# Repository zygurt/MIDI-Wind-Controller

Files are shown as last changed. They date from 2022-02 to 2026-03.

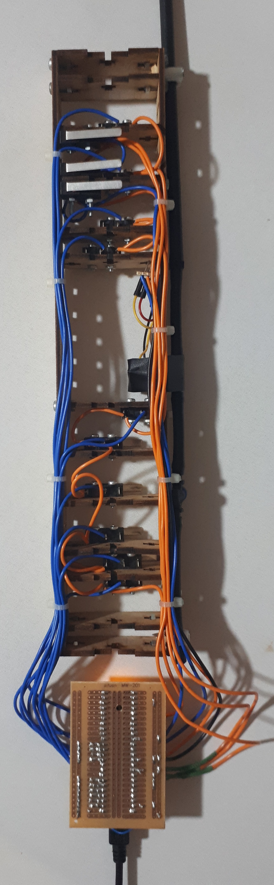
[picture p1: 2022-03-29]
images/Doppler_Sax_Back.jpg

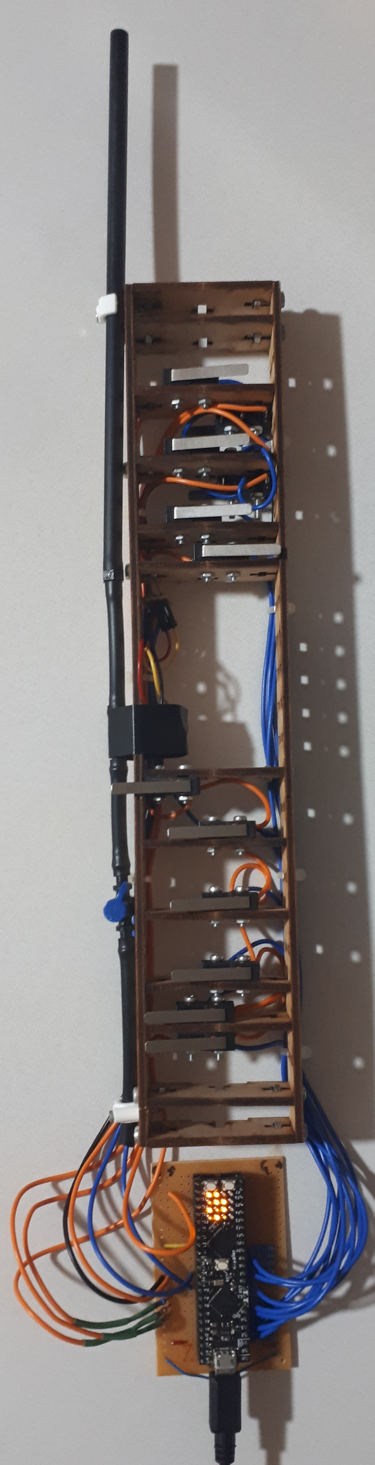
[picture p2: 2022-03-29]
images/Doppler_Sax_Front.jpg

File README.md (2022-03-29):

# MIDI-Wind-Controller

## A brief overview of the repo

- 3D designs contains dxf and svg files.  Basic design was done in Fusion 360 and then exported.
- Datasheets contains datasheets. Woah.
- src contains source code for doppler and Arduino Leonardo implementations, as well as the board schematic.  Currently midi messages are sent over USB, and shows the midi note number in binary on the LED grid on the doppler board.

## Known issues
- Pressing the low C key (D9) causes the doppler to crash.  Reducing the length of the readButtons() switch case to 7 statements stops the crashing.  The error isn't present on the Arduino Leonardo.
- The octave keys give incorrect values for C#. Top 2 octaves are swapped. Again, this error does not occur for the Arduino Leonardo.

Updates are occasionally posted on [Instagram](https://www.instagram.com/zygurt/)

## Current prototype status:
Prototype 2

## Legacy information
Videos about the initial prototype can be found on [Youtube](https://www.youtube.com/watch?v=xT4aQg9pAro&list=PLZOH4oUjroN9ol0y3P3p1gkSgcQwLBbCZ)

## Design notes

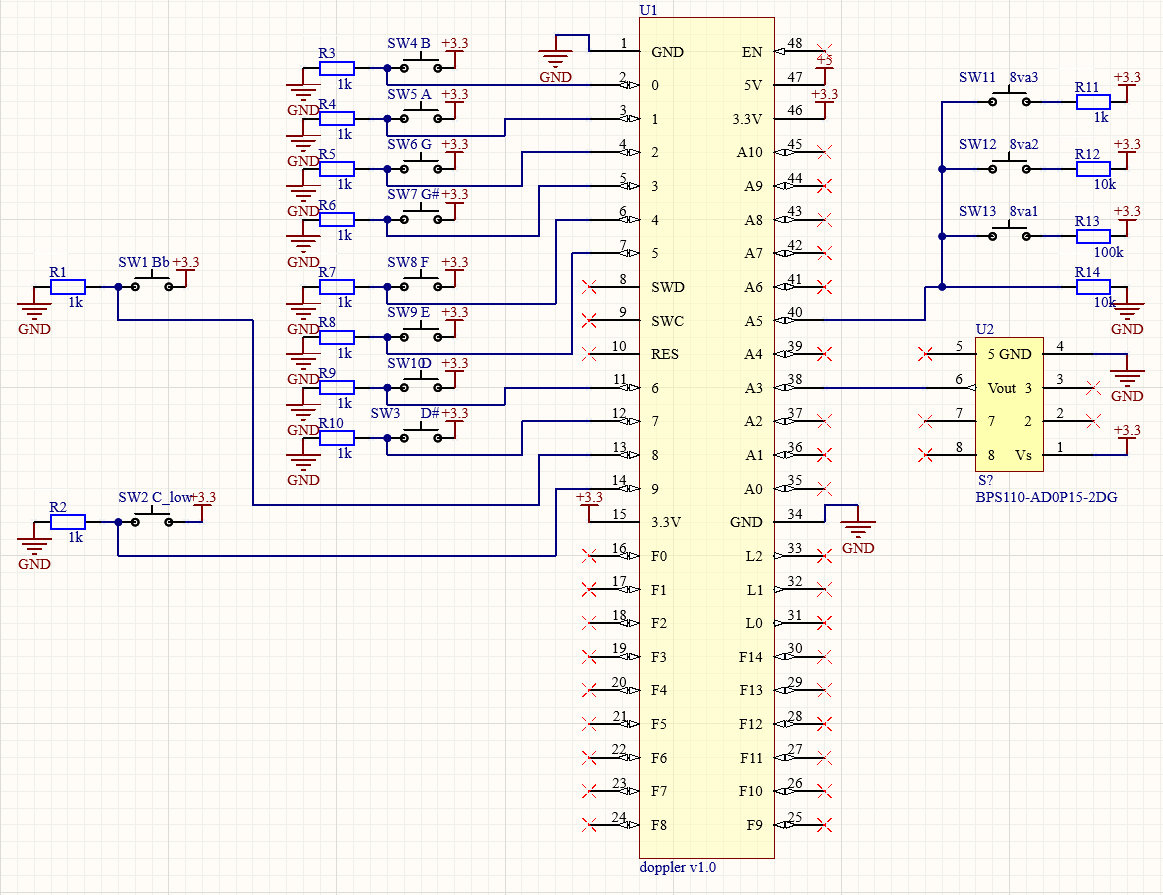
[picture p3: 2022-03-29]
src/Schematic.PNG

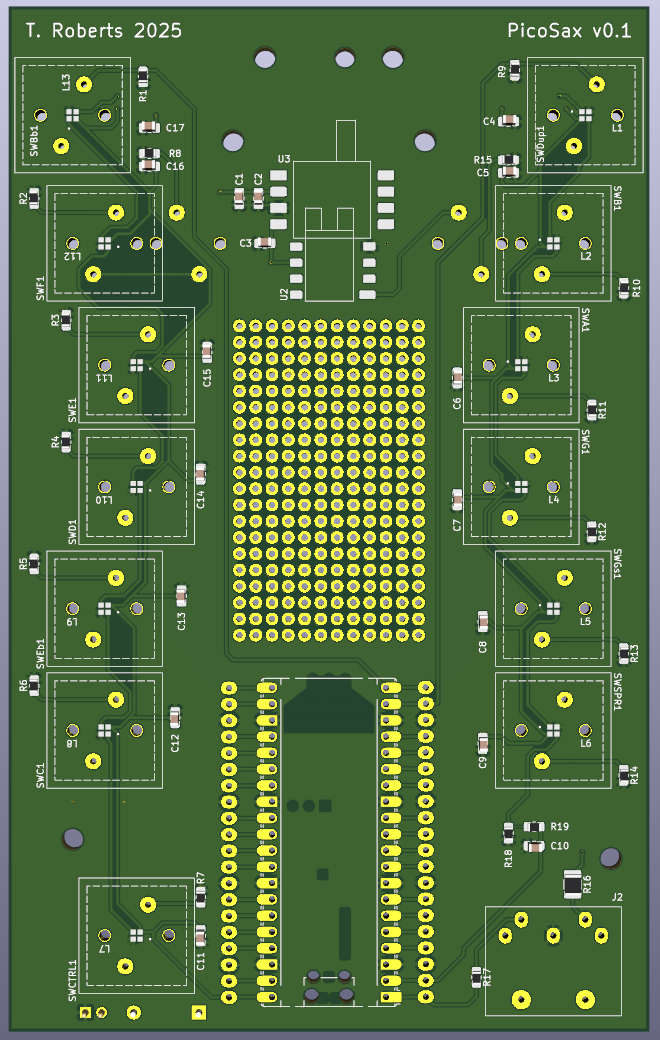
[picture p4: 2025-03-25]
pcb/PicoSax/Images/PCB_3D_Front.PNG

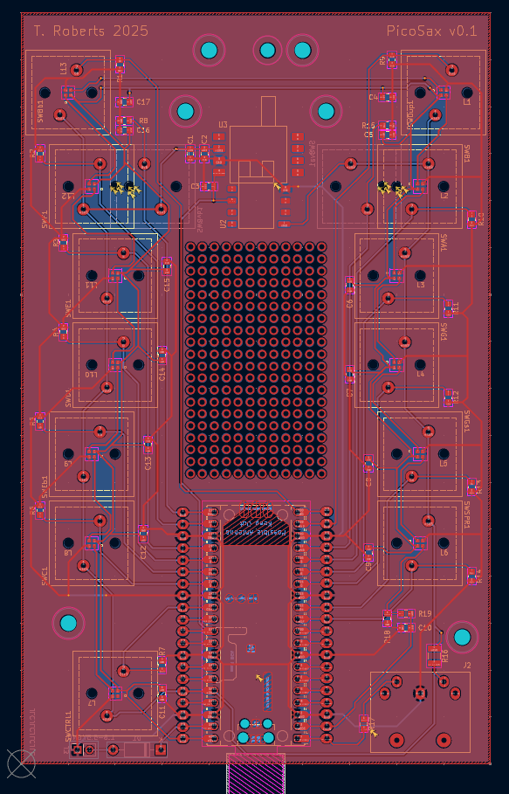
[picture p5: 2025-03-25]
pcb/PicoSax/Images/PCB_Front.PNG

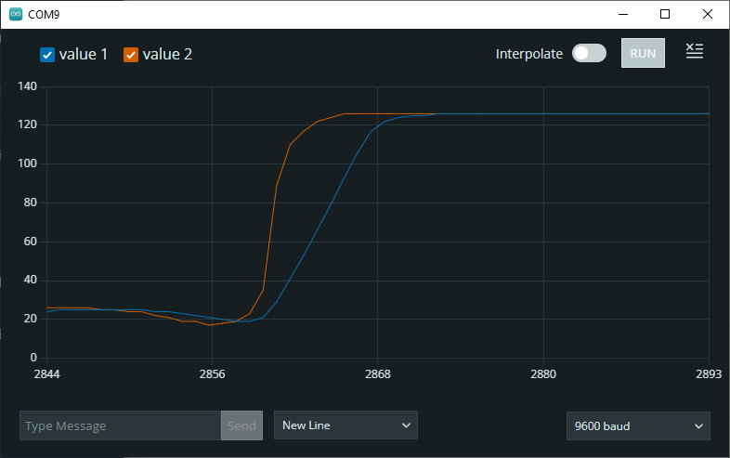
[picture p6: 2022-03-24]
src/BreathRaw_Filtered.PNG

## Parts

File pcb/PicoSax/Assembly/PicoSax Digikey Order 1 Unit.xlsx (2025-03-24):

Index | Quantity | Part Number | Manufacturer Part Number | Description | Customer Reference | Available | Backorder | Unit Price | Extended Price AUD
1 | 14 | 478-08056D104KAT2ACT-ND | 08056D104KAT2A | CAP CER 0.1UF 6.3V X5R 0805 |  | 14 | 0 | 0.07 | 0.98
2 | 1 | 311-1573-1-ND | CC0805KKX5R6BB105 | CAP CER 1UF 10V X5R 0805 |  | 1 | 0 | 0.21 | 0.21
3 | 1 | 732-8016-1-ND | 885012207006 | CAP CER 470PF 10V X7R 0805 |  | 1 | 0 | 0.16 | 0.16
4 | 1 | 732-8021-1-ND | 885012207011 | CAP CER 10000PF 10V X7R 0805 |  | 1 | 0 | 0.16 | 0.16
5 | 4 | S7018-ND | PPTC201LFBN-RC | CONN HDR 20POS 0.1 TIN PCB |  | 4 | 0 | 1.75 | 7.00
6 | 1 | 1N5817DICT-ND | 1N5817-T | DIODE SCHOTTKY 20V 1A DO41 |  | 1 | 0 | 0.35 | 0.35
7 | 1 | 2092-KCDX-5S-N2-ND | KCDX-5S-N2 | CONN RCPT FMALE MINI DIN 5P SLDR |  | 1 | 0 | 2.42 | 2.42
8 | 13 | 1080-1623-1-ND | 19-C47/RSGHBHC-5V01/2T | ADDRESS LED RED/GREEN/BLUE |  | 13 | 0 | 1.041 | 13.53
9 | 17 | RNCP0805FTD10K0CT-ND | RNCP0805FTD10K0 | RES 10K OHM 1% 1/4W 0805 |  | 17 | 0 | 0.024 | 0.41
10 | 1 | 13-RC1210FR-0733RLCT-ND | RC1210FR-0733RL | RES 33 OHM 1% 1/2W 1210 |  | 1 | 0 | 0.17 | 0.17
11 | 1 | RNCP0805FTD10R0CT-ND | RNCP0805FTD10R0 | RES 10 OHM 1% 1/4W 0805 |  | 1 | 0 | 0.16 | 0.16
12 | 1 | MP3V5004GP-ND | MP3V5004GP | SENSOR 0.57PSIG 0.13" 3V 8SOP |  | 0 | 1 | 24.47 | 24.47
 |  |  |  |  |  |  |  |  | 50.02

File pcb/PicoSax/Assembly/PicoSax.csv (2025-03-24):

Reference | Qty | Value | DNP | Exclude from BOM | Size | Footprint | Datasheet | Note | Digikey Part number | Manufacturer Part Number
A1 | 1 | RaspberryPi_Pico |  |  |  | Module:RaspberryPi_Pico_Common_Unspecified | https://datasheets.raspberrypi.com/pico/pico-datasheet.pdf
C1 | 1 | 1uF | >6.3V, X5R |  | 0805 | Capacitor_SMD:C_0805_2012Metric_Pad1.18x1.45mm_HandSolder | ~ |  | CC0805KKX5R6BB105
C2 | 1 | 0.01uF | X7R |  | 0805 | Capacitor_SMD:C_0805_2012Metric_Pad1.18x1.45mm_HandSolder | ~ |  | 885012207011
C3 | 1 | 470pF | X7R |  | 0805 | Capacitor_SMD:C_0805_2012Metric_Pad1.18x1.45mm_HandSolder | ~ |  | 885012207006
C4,C5,C6,C7,C8,C9,C10,C11,C12,C13,C14,C15,C16,C17 | 14 | 0.1uF | X5R |  | 0805 | Capacitor_SMD:C_0805_2012Metric_Pad1.18x1.45mm_HandSolder | ~ |  | 08056D104KAT2A
D1 | 1 | 1N5817 |  |  |  | Diode_THT:D_DO-41_SOD81_P10.16mm_Horizontal | http://www.vishay.com/docs/88525/1n5817.pdf |  | 1N5817DICT-ND - Cut Tape (CT)
J1,J4 | 2 | ~ |  |  | 20 Pins each | MyLibrary:PiPico Header |  |  | S7018-ND | PPTC201LFBN-RC
J2 | 1 | ~ |  |  |  | MyLibrary:MIDI_DIN5 |  |  | 2092-KCDX-5S-N2-ND | KCDX-5S-N2
J3 | 1 | Conn_01x02 | 1 |  | 2 Pin Header | Connector_PinHeader_2.54mm:PinHeader_1x02_P2.54mm_Vertical | ~
L1,L2,L3,L4,L5,L6,L7,L8,L9,L10,L11,L12,L13 | 13 | 19-C47/RSGHBHC-5V01/2T |  |  |  | MyLibrary:19-C47&slash_RSGHBHC-5V01&slash_2T_EVE-M | 19-C47/RSGHBHC-5V01/2T |  | 1080-1623-1-ND - Cut Tape (CT)
R1,R2,R3,R4,R5,R6,R7,R8,R9,R10,R11,R12,R13,R14,R15,R18,R19 | 17 | 10K |  |  | 0805 | Resistor_SMD:R_0805_2012Metric_Pad1.20x1.40mm_HandSolder | ~ |  | RNCP0805FTD10K0CT-ND
R16 | 1 | 33R 0.5W |  |  | 1210 | Resistor_THT:R_Axial_DIN0204_L3.6mm_D1.6mm_P7.62mm_Horizontal | ~ |  | RC1210FR-0733RL
R17 | 1 | 10R 0.25W |  |  | 0805 | Resistor_THT:R_Axial_DIN0204_L3.6mm_D1.6mm_P7.62mm_Horizontal | ~ |  | RNCP0805FTD10R0CT-ND
SW8va1,SW8vb1,SWA1,SWB1,SWBb1,SWC1,SWCTRL1,SWD1,SWDup1,SWE1,SWEb1,SWF1,SWG1,SWGs1,SWSPR1 | 15 | Omron_B3K_L13L |  |  |  | MyLibrary:Omron B3K L13L | ~
U1 | 1 | Perfboard | 1 |  |  | MyLibrary:Perfboard 12x20
U2 | 1 | ~ |  |  |  | MyLibrary:BPS110 AD0P15 |  | Place either U2 or U3
U3 | 1 | ~ |  |  |  | MyLibrary:MP3V5004GP |  | Place either U2 or U3 |  |  | https://au.element14.com/nxp/mp3v5004gp/pressure-sensor-0-3-92kpa-gauge/dp/2776056

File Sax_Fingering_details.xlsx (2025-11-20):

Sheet: Leonardo
Midi Note (Dec) | 73 | 72 | 71 | 70 | 69 | 68 | 67 | 66 | 65 | 64 | 63 | 62
Note | C# | C | B | A# | A | G# | G | F# | F | E | D# | D
B | 0 | 0 | 1 | 1 | 1 | 1 | 1 | 1 | 1 | 1 | 1 | 1 | LSB
A | 0 | 1 | 0 | 1 | 1 | 1 | 1 | 1 | 1 | 1 | 1 | 1
G | 0 | 0 | 0 | 0 | 0 | 1 | 1 | 1 | 1 | 1 | 1 | 1
G# | 0 | 0 | 0 | 0 | 0 | 1 | 0 | 0 | 0 | 0 | 0 | 0
F | 0 | 0 | 0 | 1 | 0 | 0 | 0 | 0 | 1 | 1 | 1 | 1
E | 0 | 0 | 0 | 0 | 0 | 0 | 0 | 1 | 0 | 1 | 1 | 1
D | 0 | 0 | 0 | 0 | 0 | 0 | 0 | 0 | 0 | 0 | 1 | 1
D# | 0 | 0 | 0 | 0 | 0 | 0 | 0 | 0 | 0 | 0 | 1 | 0 | MSB
Note Byte Val | 0 | 2 | 1 | 19 | 3 | 15 | 7 | 39 | 23 | 55 | 247 | 119
 |  |  |  |  | Using Negatives to allow for sqrt(negative)
 |  |  |  |  | 0.5 | 0.25 | 2
x | Linear | Float |  |  | float^0.5 | float^0.25 | float^2
 | -1024 | -1 |  |  | -1 | -1 | -1
 | -512 | -0.5 |  |  | -0.7071067812 | -0.8408964153 | -0.25
 | -256 | -0.25 |  |  | -0.5 | -0.7071067812 | -0.0625
 | -128 | -0.125 |  |  | -0.3535533906 | -0.5946035575 | -0.015625
 | -64 | -0.0625 |  |  | -0.25 | -0.5 | -0.00390625
 | -32 | -0.03125 |  |  | -0.1767766953 | -0.4204482076 | -0.0009765625
 | -16 | -0.015625 |  |  | -0.125 | -0.3535533906 | -0.000244140625
 | -8 | -0.0078125 |  |  | -0.08838834765 | -0.2973017788 | -6.103515625e-05
 | -4 | -0.00390625 |  |  | -0.0625 | -0.25 | -1.525878906e-05
-2 | -2 | -0.001953125 |  |  | -0.04419417382 | -0.2102241038 | -3.814697266e-06
-1 | -1 | -0.0009765625 |  |  | -0.03125 | -0.1767766953 | -9.536743164e-07
 | 0 | 0 |  |  | 0 | 0 | 0
0 | 1 | 0.0009765625 |  |  | 0.03125 | 0.1767766953 | 9.536743164e-07
1 | 2 | 0.001953125 |  |  | 0.04419417382 | 0.2102241038 | 3.814697266e-06
2 | 4 | 0.00390625 |  |  | 0.0625 | 0.25 | 1.525878906e-05
3 | 8 | 0.0078125 |  |  | 0.08838834765 | 0.2973017788 | 6.103515625e-05
4 | 16 | 0.015625 |  |  | 0.125 | 0.3535533906 | 0.000244140625
5 | 32 | 0.03125 |  |  | 0.1767766953 | 0.4204482076 | 0.0009765625
6 | 64 | 0.0625 |  |  | 0.25 | 0.5 | 0.00390625
7 | 128 | 0.125 |  |  | 0.3535533906 | 0.5946035575 | 0.015625
8 | 256 | 0.25 |  |  | 0.5 | 0.7071067812 | 0.0625
9 | 512 | 0.5 |  |  | 0.7071067812 | 0.8408964153 | 0.25
10 | 1024 | 1 |  |  | 1 | 1 | 1

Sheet: Doppler
Midi Note (Dec) | 49 | 48 | 48 | 47 | 46 | 46 | 45 | 44 | 43 | 42 | 41 | 40 | 39 | 38 | 37 | 36 |  |  | Arduino | Doppler
Note | C# | C | C | B | A# | A# | A | G# | G | F# | F | E | D# | D | C# | C |  |  | Input Pin | Input Pin
B | 0 | 0 | 1 | 1 | 1 | 1 | 1 | 1 | 1 | 1 | 1 | 1 | 1 | 1 | 1 | 1 | LSB | 0 | 2 | 0
A | 0 | 1 | 0 | 0 | 1 | 1 | 1 | 1 | 1 | 1 | 1 | 1 | 1 | 1 | 1 | 1 |  | 0 | 3 | 1
G | 0 | 0 | 0 | 0 | 0 | 0 | 0 | 1 | 1 | 1 | 1 | 1 | 1 | 1 | 1 | 1 |  | 0 | 4 | 2
G# | 0 | 0 | 0 | 0 | 0 | 0 | 0 | 1 | 0 | 0 | 0 | 0 | 0 | 0 | 1 | 0 |  | 0 | 5 | 3
F | 0 | 0 | 0 | 0 | 0 | 1 | 0 | 0 | 0 | 0 | 1 | 1 | 1 | 1 | 1 | 1 |  | 0 | 6 | 4
E | 0 | 0 | 0 | 0 | 0 | 0 | 0 | 0 | 0 | 1 | 0 | 1 | 1 | 1 | 1 | 1 |  | 0 | 7 | 5
D | 0 | 0 | 0 | 0 | 0 | 0 | 0 | 0 | 0 | 0 | 0 | 0 | 1 | 1 | 1 | 1 |  | 0 | 8 | 6
D# | 0 | 0 | 0 | 0 | 0 | 0 | 0 | 0 | 0 | 0 | 0 | 0 | 1 | 0 | 0 | 0 | MSB | 0 | 9 | 7
Bb | 0 | 0 | 1 | 0 | 1 | 0 | 0 | 0 | 0 | 0 | 0 | 0 | 0 | 0 | 0 | 0 |  | 0 | 10 | 8
C | 0 | 0 | 0 | 0 | 0 | 0 | 0 | 0 | 0 | 0 | 0 | 0 | 0 | 0 | 1 | 1 |  | 1 | 11 | 9
Note Byte Val | 0 | 2 | 257 | 1 | 259 | 19 | 3 | 15 | 7 | 39 | 23 | 55 | 247 | 119 | 639 | 631 |  | 512
Octave Calculations |  | VDD | 3.3
R1 | R2 | Vout | AnalogRead | Thresholds | Midi Adjust | Octave Adjust
1000 | 10000 | 3.02 | 937.1151515 | 726.1090909 | +36 | +3 Octaves
10000 | 10000 | 1.66 | 515.1030303 | 304.0969697 | +24 | +2 Octave
100000 | 10000 | 0.3 | 93.09090909 | 64.04545455 | +0 | 0 Octave
 |  |  | 35 | 17.5 | +12 | +1 Home Octave With no buttons pressed
G# Held down alternative fingerings
Midi Note (Dec) | 49 | 48 |  | 47 | 46 | 46 | 45 |  |  | 42 | 41 | 40 | 39 | 38
Note | C# | C |  | B | A# | A# | A |  |  | F# | F | E | D# | D
B | 0 | 0 |  | 1 | 1 | 1 | 1 |  |  | 1 | 1 | 1 | 1 | 1
A | 0 | 1 |  | 0 | 1 | 1 | 1 |  |  | 1 | 1 | 1 | 1 | 1
G | 0 | 0 |  | 0 | 0 | 0 | 0 |  |  | 1 | 1 | 1 | 1 | 1
G# | 1 | 1 |  | 1 | 1 | 1 | 1 |  |  | 1 | 1 | 1 | 1 | 1
F | 0 | 0 |  | 0 | 0 | 1 | 0 |  |  | 0 | 1 | 1 | 1 | 1
E | 0 | 0 |  | 0 | 0 | 0 | 0 |  |  | 1 | 0 | 1 | 1 | 1
D | 0 | 0 |  | 0 | 0 | 0 | 0 |  |  | 0 | 0 | 0 | 1 | 1
D# | 0 | 0 |  | 0 | 0 | 0 | 0 |  |  | 0 | 0 | 0 | 1 | 0
Bb | 0 | 0 |  | 0 | 1 | 0 | 0 |  |  | 0 | 0 | 0 | 0 | 0
C | 0 | 0 |  | 0 | 0 | 0 | 0 |  |  | 0 | 0 | 0 | 0 | 0
Note Byte Val | 8 | 10 |  | 9 | 267 | 27 | 11 |  |  | 47 | 31 | 63 | 255 | 127
MODES
Note | Enter Menu Mode | Leave Menu Mode | Octave Up | Octave Down |  | Semitone Up | Semitone Down |  | Bb | Concert | Eb
B | 0 | 0 | 0 | 0 |  | 0 | 0 |  | 1 | 0 | 0
A | 0 | 0 | 0 | 0 |  | 0 | 0 |  | 0 | 1 | 0
G | 0 | 0 | 0 | 0 |  | 0 | 0 |  | 0 | 0 | 1
G# | 0 | 0 | 0 | 0 |  | 1 | 0 |  | 0 | 0 | 0
F | 0 | 0 | 0 | 0 |  | 0 | 0 |  | 0 | 0 | 0
E | 0 | 0 | 0 | 0 |  | 0 | 0 |  | 0 | 0 | 0
D | 0 | 1 | 0 | 0 |  | 0 | 0 |  | 0 | 0 | 0
D# | 1 | 0 | 1 | 0 |  | 0 | 0 |  | 0 | 0 | 0
Bb | 0 | 0 | 0 | 0 |  | 0 | 1 |  | 0 | 0 | 0
C | 1 | 0 | 0 | 1 |  | 0 | 0 |  | 0 | 0 | 0
Note Byte Val | 640 | 64 | 128 | 512 |  | 8 | 256 |  | 1 | 2 | 4

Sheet: PicoSax
Midi Note (Dec) | 49 | 48 | 47 | 46 | 45 | 44 | 43 | 42 | 41 | 40 | 39 | 38 | 37 | 36
Note | C# | C | B | A# | A | G# | G | F# | F | E | D# | D | C# | C
Dup | 0
B | 0 |  | 1 | 1 | 1 | 1 | 1 | 1 | 1 | 1 | 1 | 1 | 1 | 1
A | 0 | 1 |  | 1 | 1 | 1 | 1 | 1 | 1 | 1 | 1 | 1 | 1 | 1
G | 0 |  |  |  |  | 1 | 1 | 1 | 1 | 1 | 1 | 1 | 1 | 1
Gs | 0 |  |  |  |  | 1 |  |  |  |  |  |  | 1
Spr | 0
Bb | 0 |  |  | 1
F | 0 |  |  |  |  |  |  |  | 1 | 1 | 1 | 1 | 1 | 1
E | 0 |  |  |  |  |  |  | 1 |  | 1 | 1 | 1 | 1 | 1
D | 0 |  |  |  |  |  |  |  |  |  | 1 | 1 | 1 | 1
Eb | 0 |  |  |  |  |  |  |  |  |  | 1
C | 0 |  |  |  |  |  |  |  |  |  |  |  | 1 | 1
Note Byte Val | 0 | 4 | 2 | 70 | 6 | 30 | 14 | 270 | 142 | 398 | 1934 | 910 | 2974 | 2958
Octave Adjustments | 8vb | 8va | 16va
8va |  | 1 | 1
8vb | 1 |  | 1
 | 2 | 1 | 3
Ctrl
Alternate Fingering |  |  |  |  |  | G# fingerings |  |  |  |  |  |  |  |  |  |  |  | Can't Do either of these
Midi Note | 48 | 46 |  | 50 |  | 49 | 48 | 47 | 46 | 46 | 46 | 45 | 42 | 41 | 40 | 39 | 38 | 37 | 36
Note | C | Bb | Bb | Dup |  | C# | C | B | A# | A# | A# | A | F# | F | E | D# | D | C# | C
Dup |  |  |  | 1 |  | 0
B | 1 | 1 | 1 |  |  | 0 |  | 1 | 1 | 1 | 1 | 1 | 1 | 1 | 1 | 1 | 1 | 1 | 1
A |  |  | 1 |  |  | 0 | 1 |  | 1 |  | 1 | 1 | 1 | 1 | 1 | 1 | 1 | 1 | 1
G |  |  |  |  |  | 0 |  |  |  |  |  |  | 1 | 1 | 1 | 1 | 1 | 1 | 1
Gs |  |  |  |  |  | 1 | 1 | 1 | 1 | 1 | 1 | 1 | 1 | 1 | 1 | 1 | 1 | 1 | 1
Spr |  |  |  |  |  | 0
Bb | 1 |  |  |  |  | 0 |  |  | 1 | 1
F |  | 1 | 1 |  |  | 0 |  |  |  |  | 1 |  |  | 1 | 1 | 1 | 1 | 1 | 1
E |  |  |  |  |  | 0 |  |  |  |  |  |  | 1 |  | 1 | 1 | 1 | 1 | 1
D |  |  |  |  |  | 0 |  |  |  |  |  |  |  |  |  | 1 | 1 | 1 | 1
Eb |  |  |  |  |  | 0 |  |  |  |  |  |  |  |  |  | 1
C |  |  |  |  |  | 0 |  |  |  |  |  |  |  |  |  |  |  | 1 | 1
Note Byte Value | 66 | 130 | 134 | 1 |  | 16 | 20 | 18 | 86 | 82 | 150 | 22 | 286 | 158 | 414 | 1950 | 926 | 2974 | 2974
MODES |  |  |  |  |  |  |  |  |  | MIDI
Note | Enter Menu Mode | Leave Menu Mode | Octave Up | Octave Down |  | Bb | Concert | Eb |  | Learn CC1 | Learn CC2 |  |  |  |  |  |  | GPIO
Dup | 0 | 0 | 0 | 0 |  | 0 | 0 | 0 |  | 0 | 0 |  |  |  |  |  |  | 14
B | 0 | 0 | 0 | 0 |  | 0 | 0 | 0 |  | 1 | 0 |  |  |  |  |  |  | 12
A | 0 | 0 | 0 | 0 |  | 0 |  | 0 |  | 0 | 1 |  |  |  |  |  |  | 11
G | 0 | 0 | 0 | 0 |  | 0 | 0 | 0 |  | 0 | 0 |  |  |  |  |  |  | 10
Gs | 0 | 0 | 0 | 0 |  | 0 | 0 | 0 |  | 0 | 0 |  |  |  |  |  |  | 9
Spr |  | 1 |  | 0 |  | 0 | 0 | 0 |  | 0 | 0 |  |  |  |  |  |  | 8
Bb | 0 | 0 | 0 | 0 |  | 1 | 0 | 0 |  | 0 | 0 |  |  |  |  |  |  | 15
F | 0 | 0 | 0 | 0 |  | 0 | 0 | 0 |  | 0 | 0 |  |  |  |  |  |  | 17
E | 0 | 0 | 0 | 0 |  | 0 | 0 | 0 |  | 0 | 0 |  |  |  |  |  |  | 18
D | 0 | 0 | 0 | 0 |  | 0 | 0 | 0 |  | 0 | 0 |  |  |  |  |  |  | 19
Eb | 0 | 0 | 0 | 0 |  | 0 | 0 | 1 |  | 0 | 0 |  |  |  |  |  |  | 20
C | 0 | 0 | 0 |  |  | 0 | 1 | 0 |  | 0 | 0 |  |  |  |  |  |  | 21
Ctrl | 1 | 0 |  |  |  |  |  |  |  | 0 | 0 |  |  |  |  |  |  | 22
8va |  |  | 1 |  |  |  |  |  |  | 0 | 0 |  |  |  |  |  |  | 13
8vb |  |  |  | 1 |  |  |  |  |  | 0 | 0 |  |  |  |  |  |  | 16
Note Byte Value | 4096 | 32 | 8192 | 16384 |  | 64 | 2048 | 1024 |  | 2 | 4

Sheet: BOM
Part | Manufacturer | Part Number | Cost / item | Number | Total Cost | Note | Link
Breath Pressure Sensor | NXP | MP3V-5004G-C6U | 21.36 | 1 | 21.36 | SMD | https://au.element14.com/nxp/mp3v5004gc6u/pressure-sensor-3-92kpa-0-to-85deg/dp/3370172?st=mp3v%205004g
Breath Pressure Sensor | NXP | MP3V-5004G-C7U |  | 1 | 0 | Thru-hole
Breath Pressure Sensor | NXP | MP3V5004GP | 15.39 | 1 |  | SMD | https://www.digikey.com.au/en/products/detail/nxp-usa-inc/MP3V5004GP/2186181

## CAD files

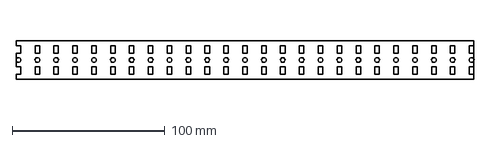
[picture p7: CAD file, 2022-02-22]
3D designs/Side.dxf
300.2 x 25.0 mm

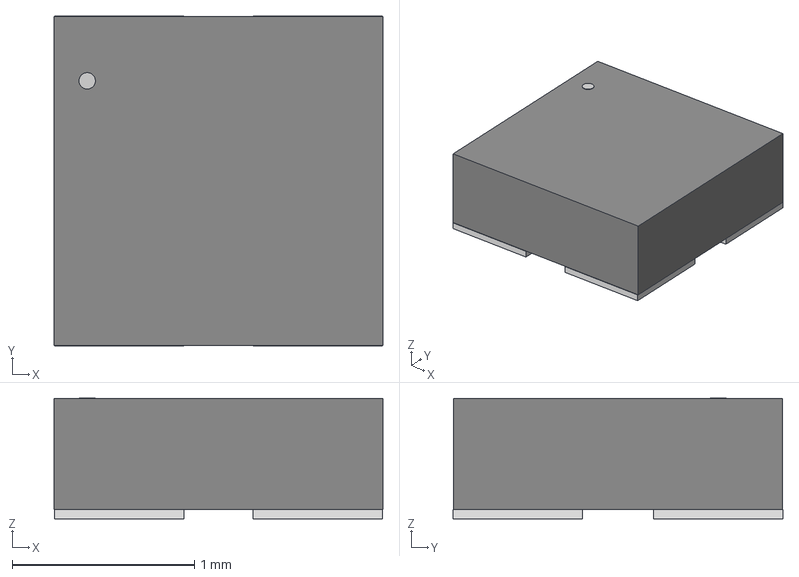
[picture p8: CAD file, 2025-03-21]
pcb/PicoSax/Parts/19_C47_RSGHBHC_5V01_2T/19-C47RSGHBHC-5V012T_EVE.step
1.80 x 1.81 x 0.663 mm

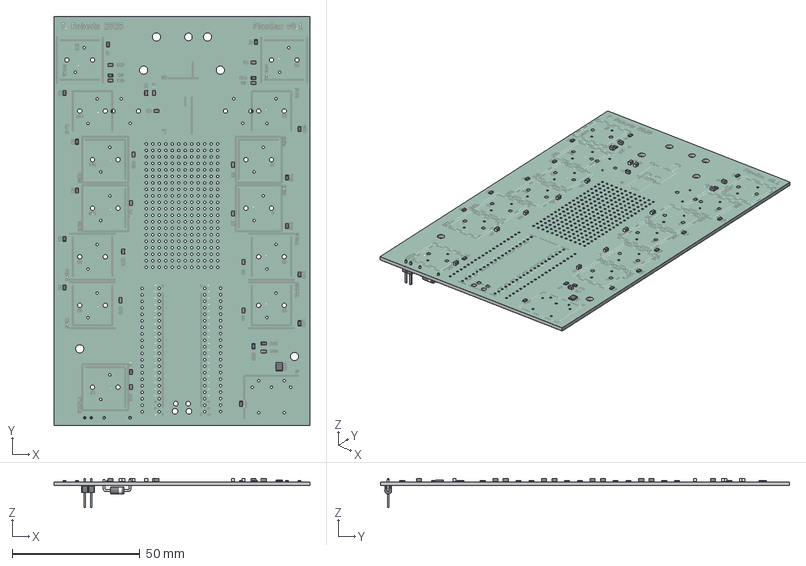
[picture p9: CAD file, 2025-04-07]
pcb/PicoSax/PicoSax.step
100.0 x 160.0 x 11.5 mm
R_0805_2012Metric x 18
C_0805_2012Metric x 17
R_1210_3225Metric
PinHeader_1x02_P2.54mm_Vertical
D_DO-41_SOD81_P10.16mm_Horizontal
PicoSax_silkscreen
PicoSax_soldermask
PicoSax_PCB

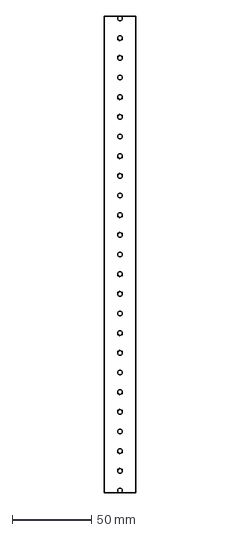
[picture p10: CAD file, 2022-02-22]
3D designs/Bottom.dxf
20.0 x 300.1 mm

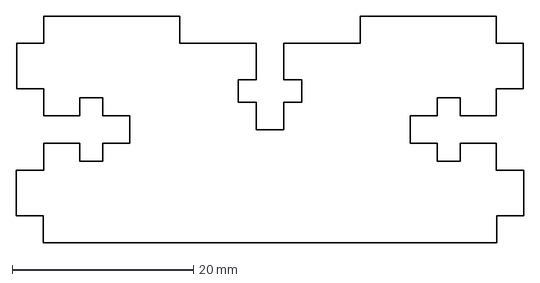
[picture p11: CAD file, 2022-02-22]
3D designs/Middle.dxf
56.0 x 25.0 mm

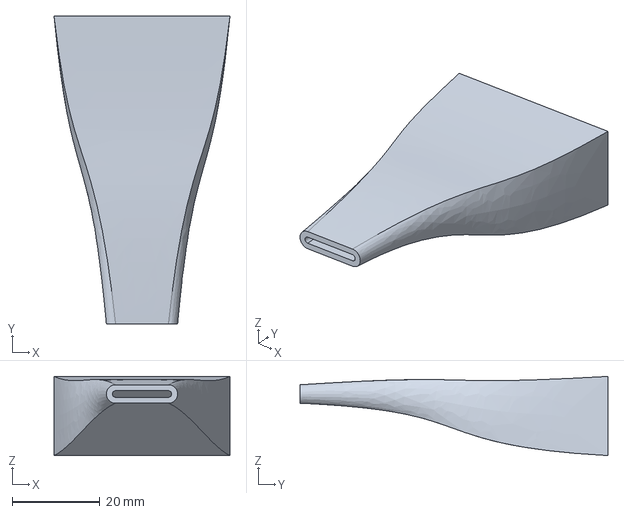
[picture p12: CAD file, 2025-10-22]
3D designs/PicoSax/MouthpieceV5.FCStd
40.0 x 70.0 x 18.0 mm

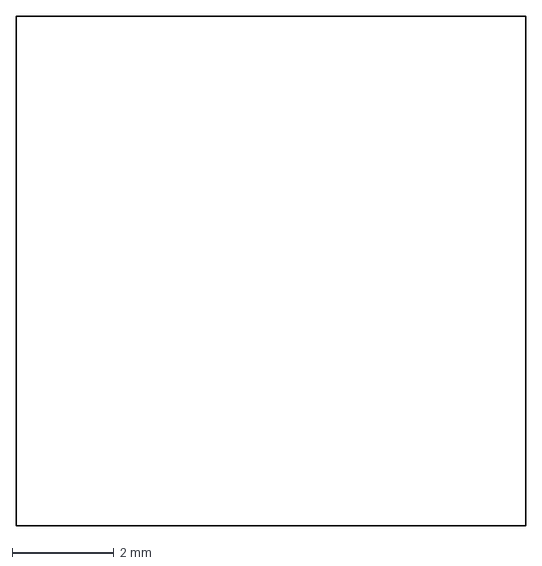
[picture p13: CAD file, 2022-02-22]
3D designs/10mmsquare.dxf
10.0 x 10.0 mm

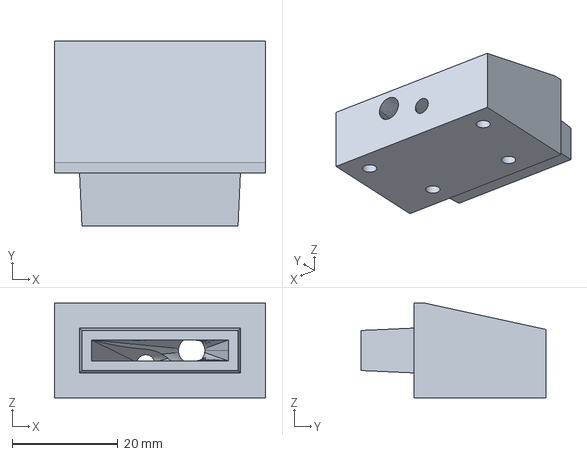
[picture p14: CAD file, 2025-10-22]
3D designs/PicoSax/Mouthpiece_Block_Test.FCStd
40.0 x 35.0 x 18.0 mm

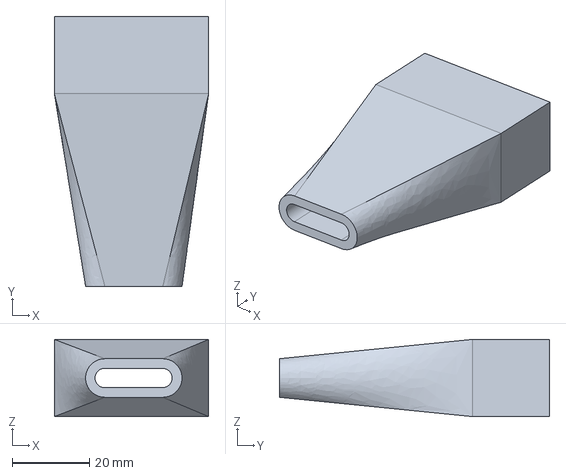
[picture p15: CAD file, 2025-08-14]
3D designs/PicoSax/MouthpieceTest.FCStd
40.0 x 70.0 x 20.0 mm

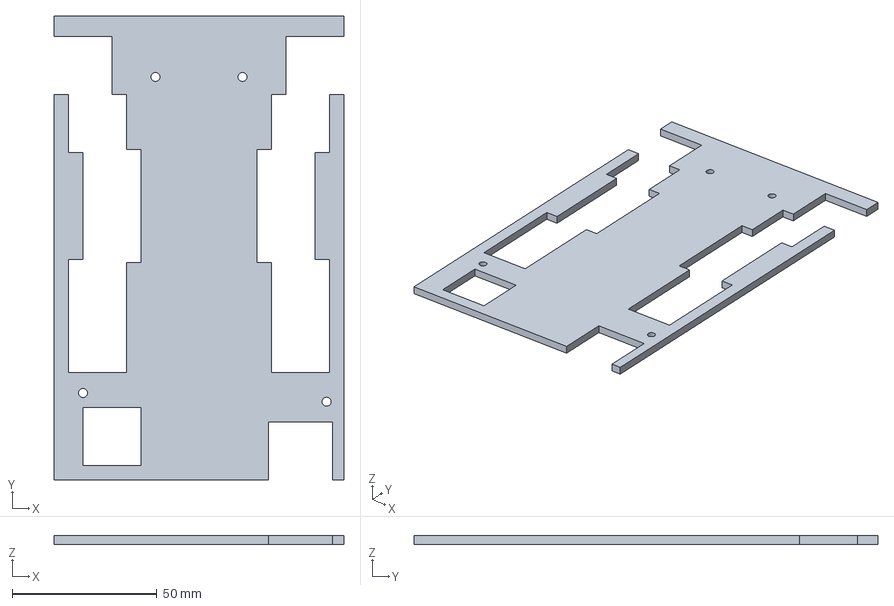
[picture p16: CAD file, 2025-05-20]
3D designs/PicoSax/Top.FCStd
100.0 x 160.0 x 3.00 mm

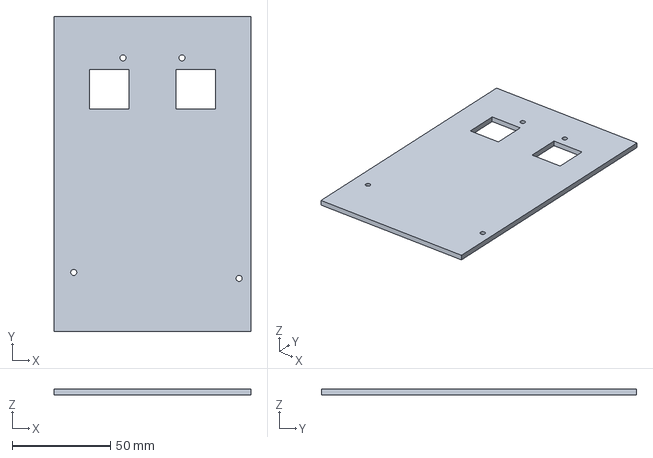
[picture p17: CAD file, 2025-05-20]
3D designs/PicoSax/Bottom.FCStd
100.0 x 160.0 x 3.00 mm

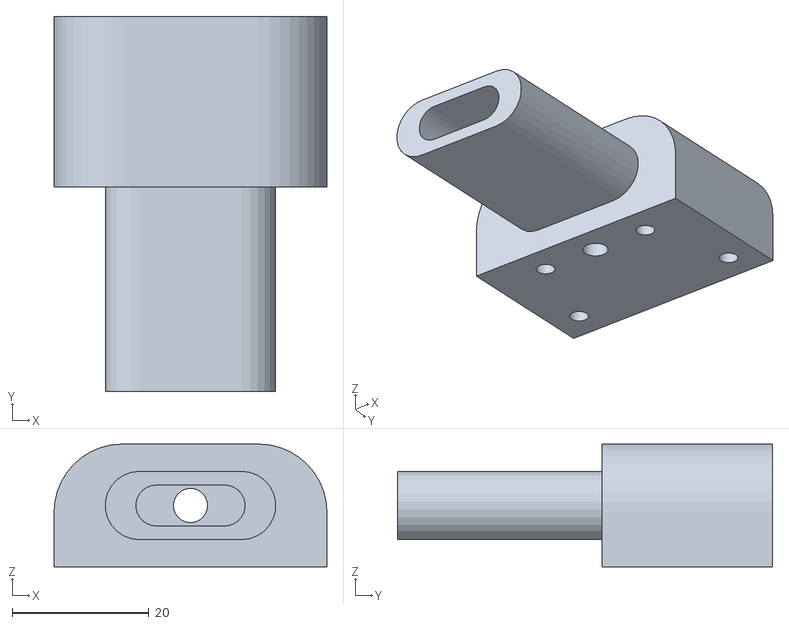
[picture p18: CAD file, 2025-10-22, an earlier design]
3D designs/PicoSax/MouthpieceV3-Body.stl
40.0 x 55.0 x 18.0

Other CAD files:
3D designs/PicoSax/Mouthpiece_Block_Test-Body.stl
3D designs/PicoSax/MouthpieceV4_Block.FCStd
3D designs/PicoSax/MouthpieceV5-Body.stl
3D designs/PicoSax/PicoSaxv0.1.FCStd
3D designs/PicoSax/PCB.FCStd
3D designs/PicoSax/MouthpieceV3.FCStd
3D designs/PicoSax/MouthpieceV2.FCStd
3D designs/PicoSax/MouthpieceV4.FCStd

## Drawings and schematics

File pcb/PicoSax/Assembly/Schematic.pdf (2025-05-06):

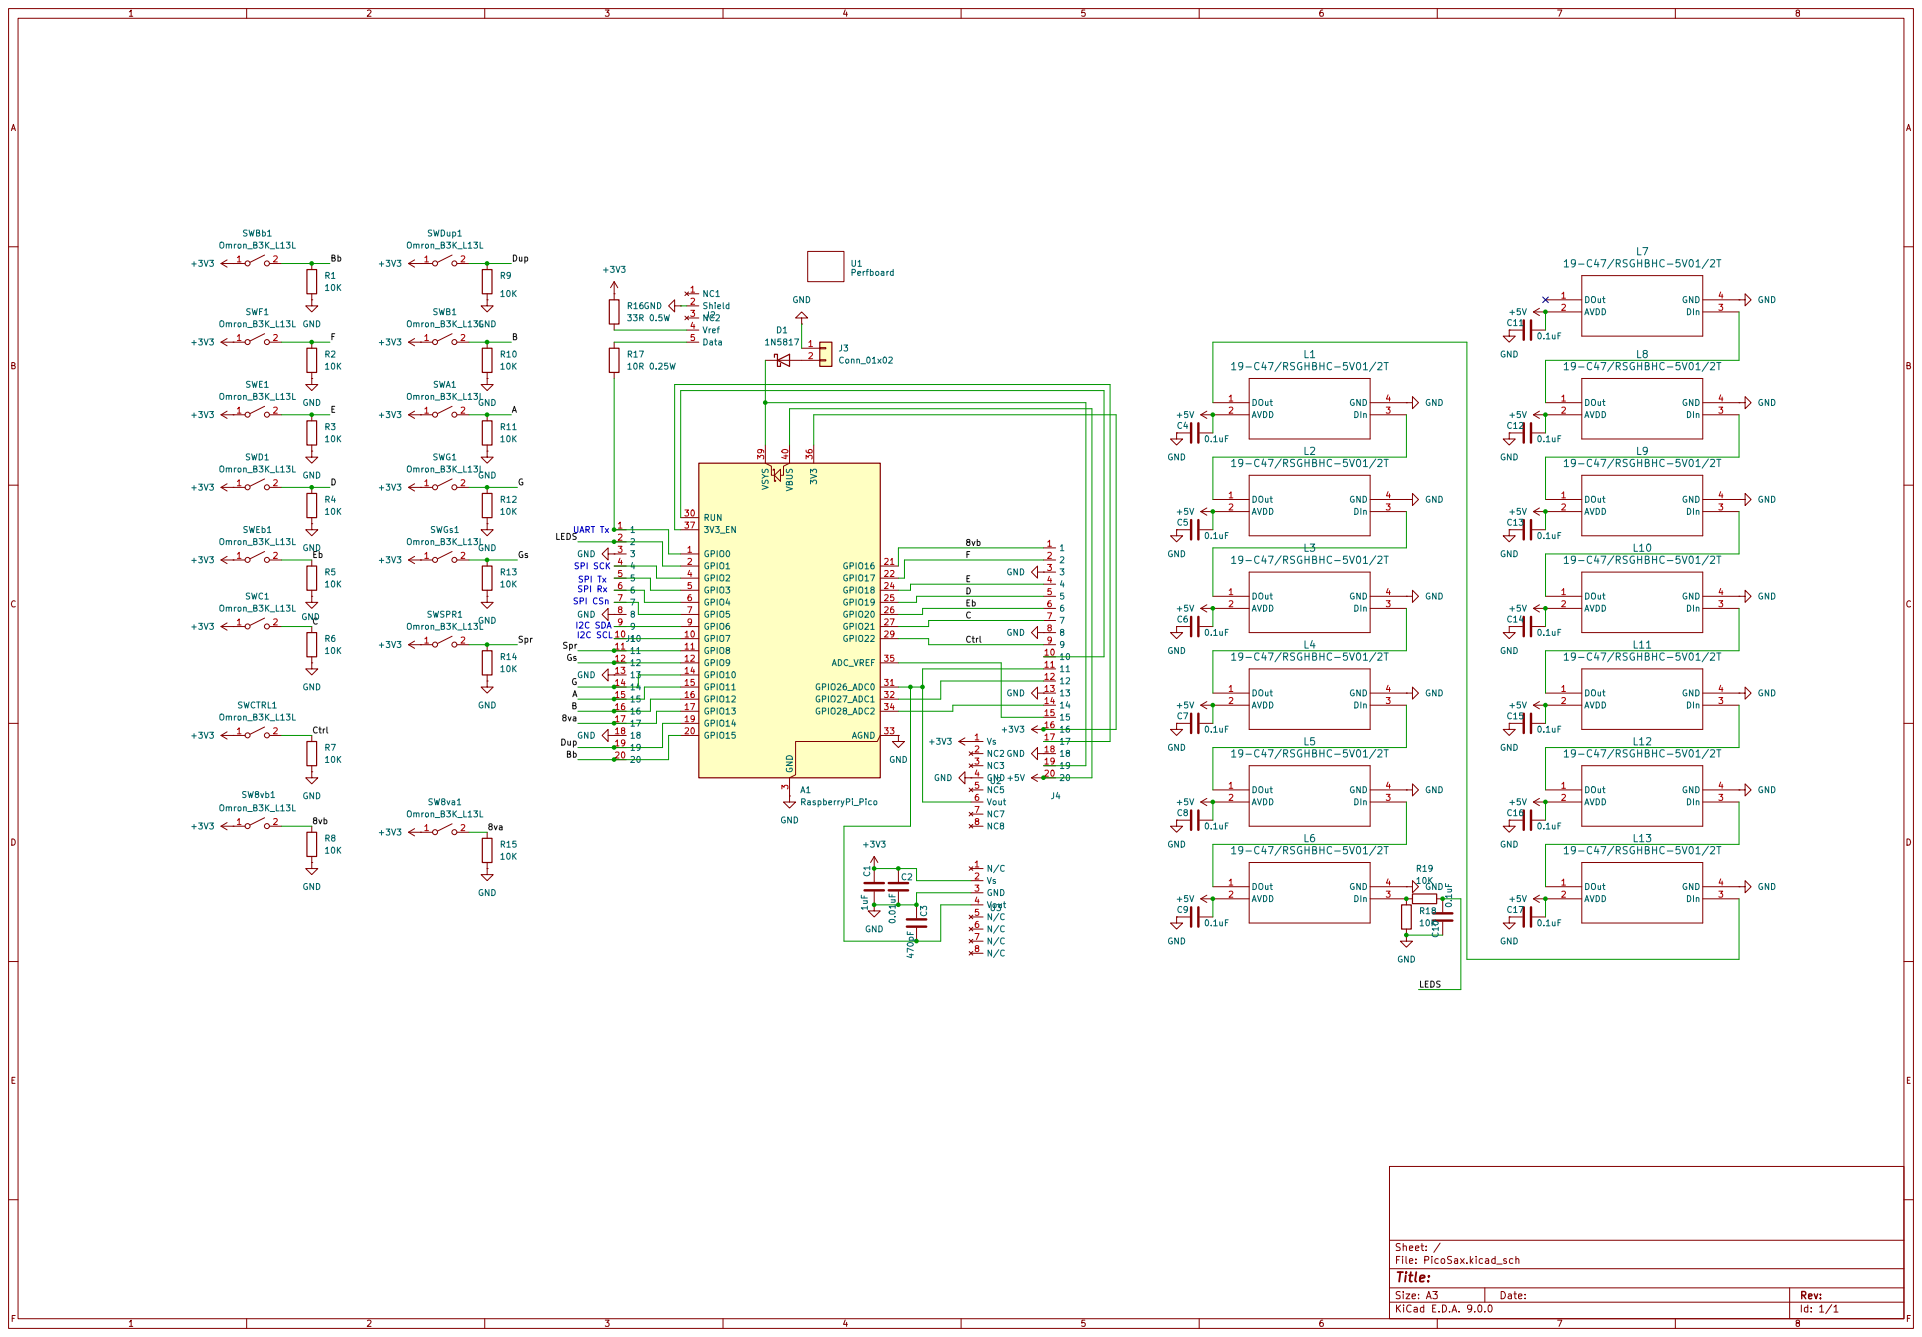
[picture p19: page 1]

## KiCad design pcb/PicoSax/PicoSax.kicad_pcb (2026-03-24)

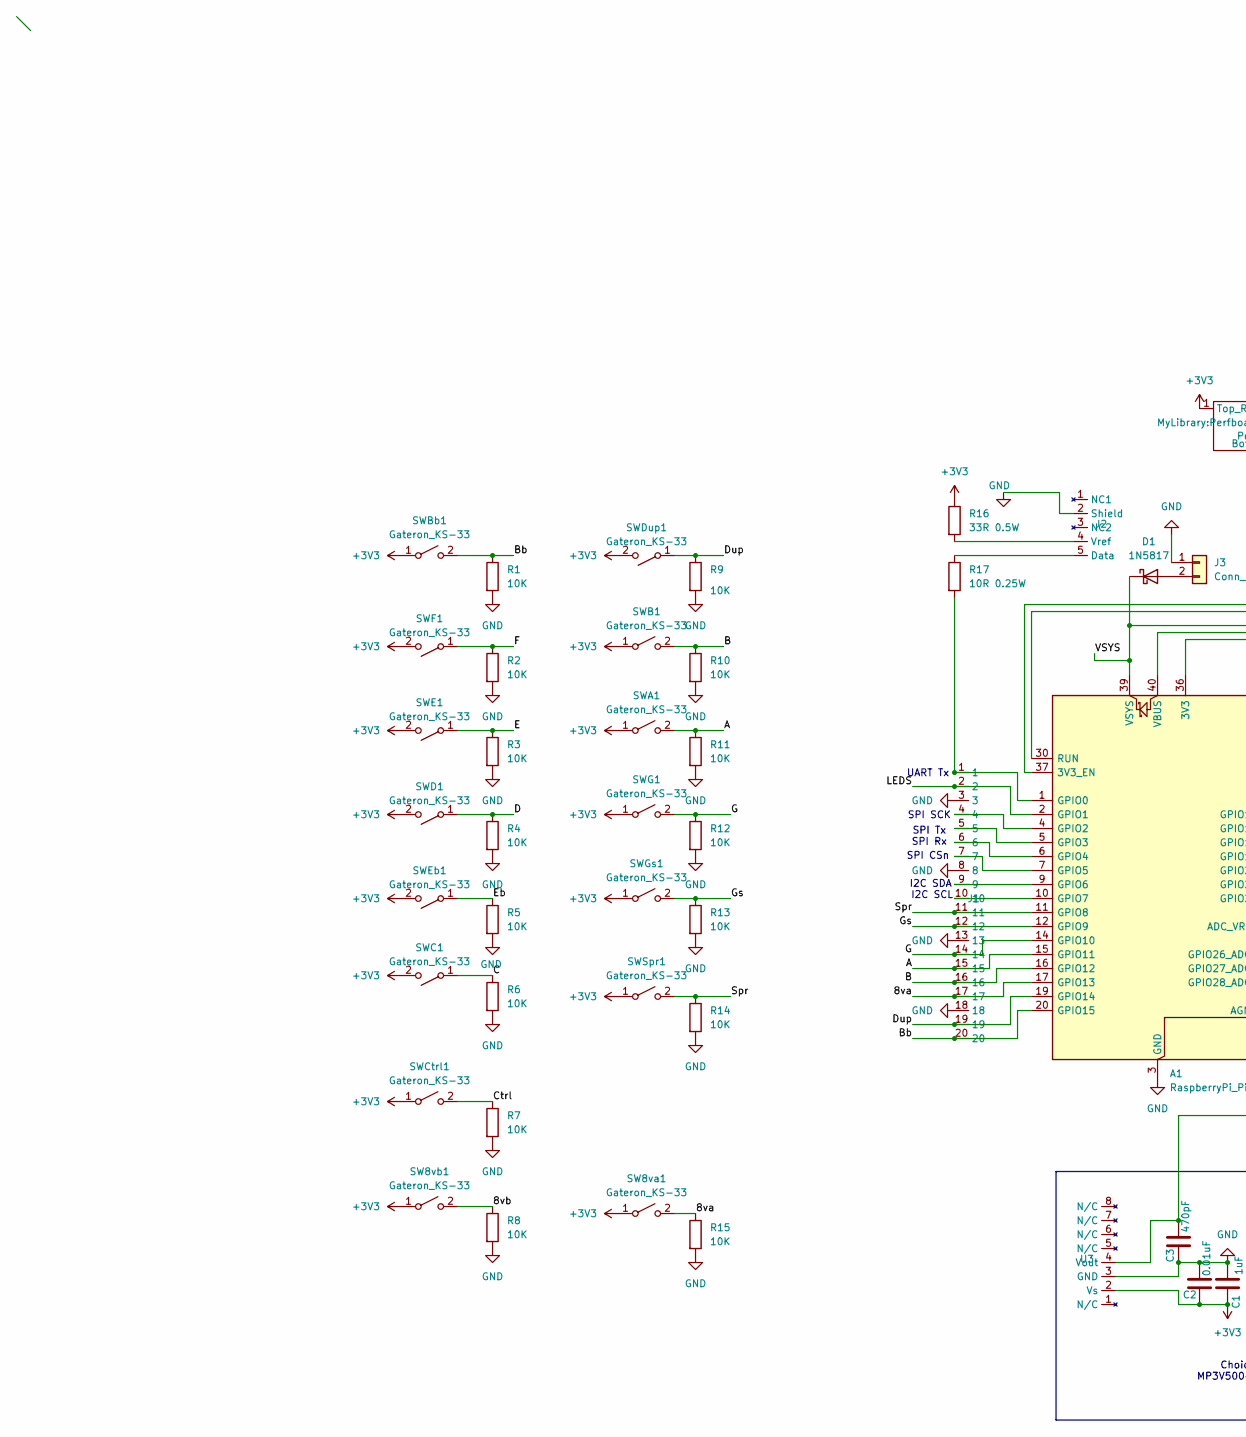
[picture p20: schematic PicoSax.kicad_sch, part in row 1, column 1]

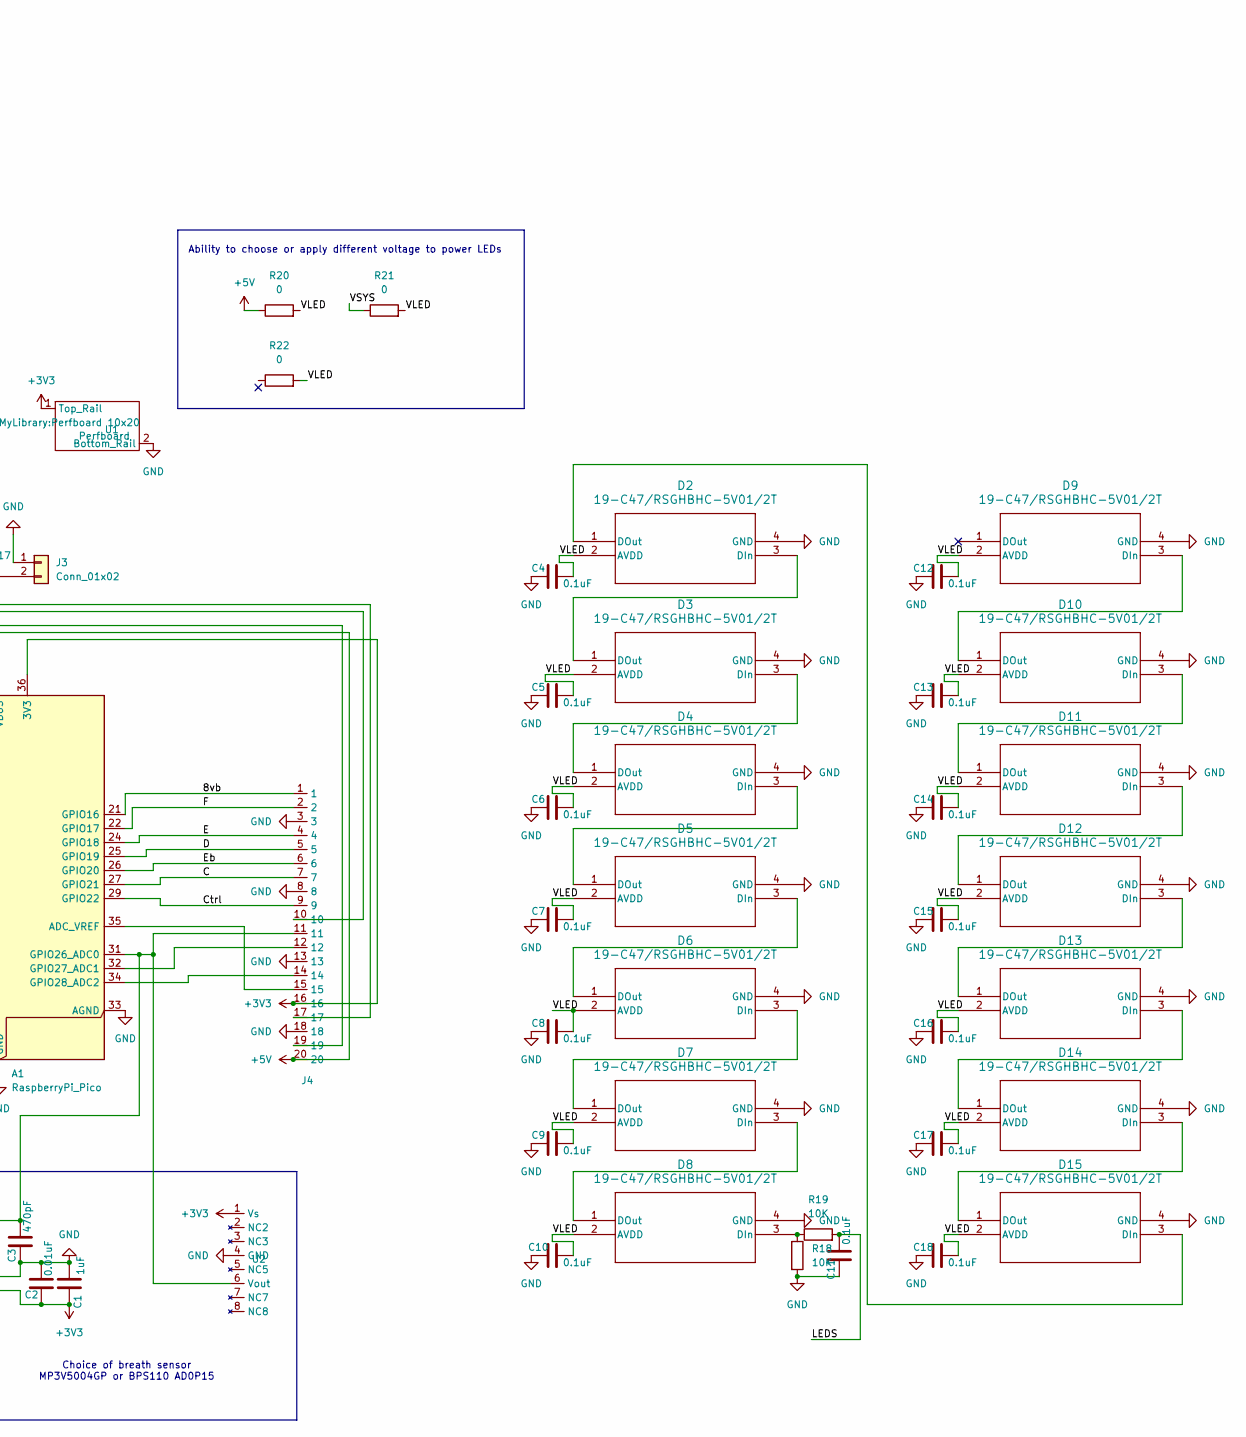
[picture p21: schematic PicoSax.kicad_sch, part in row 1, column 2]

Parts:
A1: RaspberryPi_Pico; RaspberryPi_Pico_Common_Unspecified
C1: 1uF; C_0805_2012Metric_Pad1.18x1.45mm_HandSolder
C2: 0.01uF; C_0805_2012Metric_Pad1.18x1.45mm_HandSolder
C3: 470pF; C_0805_2012Metric_Pad1.18x1.45mm_HandSolder
C4, C5, C6, C7, C8, C9, C10, C11, C12, C13, C14, C15, C16, C17, C18: 0.1uF; C_0805_2012Metric_Pad1.18x1.45mm_HandSolder
D1: 1N5817; D_DO-41_SOD81_P10.16mm_Horizontal
D2, D3, D4, D5, D6, D7, D8, D9, D10, D11, D12, D13, D14, D15: 19-C47/RSGHBHC-5V01/2T; 19-C47_RSGHBHC-5V01-2T
J1, J4: PiPico Header
J2: MIDI_DIN5
J3: Conn_01x02; PinHeader_1x02_P2.54mm_Vertical
R1, R2, R3, R4, R5, R6, R7, R8, R9, R10, R11, R12, R13, R14, R15, R18, R19: 10K; R_0805_2012Metric_Pad1.20x1.40mm_HandSolder
R16: 33R 0.5W; R_1210_3225Metric_Pad1.30x2.65mm_HandSolder
R17: 10R 0.25W; R_0805_2012Metric_Pad1.20x1.40mm_HandSolder
R20, R21, R22: 0; R_0805_2012Metric_Pad1.20x1.40mm_HandSolder
SW8va1, SW8vb1: Gateron_KS-33; KS-33
SWA1: Gateron_KS-33; KS-33
SWB1: Gateron_KS-33; KS-33
SWBb1: Gateron_KS-33; KS-33
SWC1: Gateron_KS-33; KS-33
SWCtrl1: Gateron_KS-33; KS-33
SWD1: Gateron_KS-33; KS-33
SWDup1: Gateron_KS-33; KS-33
SWE1: Gateron_KS-33; KS-33
SWEb1: Gateron_KS-33; KS-33
SWF1: Gateron_KS-33; KS-33
SWG1: Gateron_KS-33; KS-33
SWGs1: Gateron_KS-33; KS-33
SWSpr1: Gateron_KS-33; KS-33
U1: Perfboard; Perfboard 10x20
U2: BPS110 AD0P15
U3: MP3V5004GP

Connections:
+3V3: A1.36 (3V3), C1.2, C2.2, J4.16, R16.1, SW8va1.1 (A), SW8vb1.1 (A), SWA1.1 (A), SWB1.1 (A), SWBb1.1 (A), SWC1.2 (B), SWCtrl1.1 (A), SWD1.2 (B), SWDup1.2 (B), SWE1.2 (B), SWEb1.2 (B), SWF1.2 (B), SWG1.1 (A), SWGs1.1 (A), SWSpr1.1 (A), U1.1 (Top_Rail), U2.1 (Vs), U3.2 (Vs)
+5V: A1.40 (VBUS), J4.20, R20.1
/8va: A1.17 (GPIO13), J1.17, R15.1, SW8va1.2 (B)
/8vb: A1.21 (GPIO16), J4.1, R8.1, SW8vb1.2 (B)
/A: A1.15 (GPIO11), J1.15, R11.1, SWA1.2 (B)
/B: A1.16 (GPIO12), J1.16, R10.1, SWB1.2 (B)
/Bb: A1.20 (GPIO15), J1.20, R1.1, SWBb1.2 (B)
/C: A1.27 (GPIO21), J4.7, R6.1, SWC1.1 (A)
/Ctrl: A1.29 (GPIO22), J4.9, R7.1, SWCtrl1.2 (B)
/D: A1.25 (GPIO19), J4.5, R4.1, SWD1.1 (A)
/Dup: A1.19 (GPIO14), J1.19, R9.1, SWDup1.1 (A)
/E: A1.24 (GPIO18), J4.4, R3.1, SWE1.1 (A)
/Eb: A1.26 (GPIO20), J4.6, R5.1, SWEb1.1 (A)
/F: A1.22 (GPIO17), J4.2, R2.1, SWF1.1 (A)
/G: A1.14 (GPIO10), J1.14, R12.1, SWG1.2 (B)
/Gs: A1.12 (GPIO9), J1.12, R13.1, SWGs1.2 (B)
/LEDS: A1.2 (GPIO1), C11.1, J1.2, R19.2
/Spr: A1.11 (GPIO8), J1.11, R14.1, SWSpr1.2 (B)
/VLED: C4.1, C5.1, C6.1, C7.1, C8.1, C9.1, C10.1, C12.1, C13.1, C14.1, C15.1, C16.1, C17.1, C18.1, D2.2 (AVDD), D3.2 (AVDD), D4.2 (AVDD), D5.2 (AVDD), D6.2 (AVDD), D7.2 (AVDD), D8.2 (AVDD), D9.2 (AVDD), D10.2 (AVDD), D11.2 (AVDD), D12.2 (AVDD), D13.2 (AVDD), D14.2 (AVDD), D15.2 (AVDD), R20.2, R21.2, R22.2
/VSYS: A1.39 (VSYS), D1.1 (K), J4.19, R21.1
GND: A1.3 (GND), A1.8 (GND), A1.13 (GND), A1.18 (GND), A1.23 (GND), A1.28 (GND), A1.33 (AGND), A1.38 (GND), C1.1, C2.1, C3.2, C4.2, C5.2, C6.2, C7.2, C8.2, C9.2, C10.2, C11.2, C12.2, C13.2, C14.2, C15.2, C16.2, C17.2, C18.2, D2.4 (GND), D3.4 (GND), D4.4 (GND), D5.4 (GND), D6.4 (GND), D7.4 (GND), D8.4 (GND), D9.4 (GND), D10.4 (GND), D11.4 (GND), D12.4 (GND), D13.4 (GND), D14.4 (GND), D15.4 (GND), J1.3, J1.8, J1.13, J1.18, J2.2 (Shield), J3.1, J4.3, J4.8, J4.13, J4.18, R1.2, R2.2, R3.2, R4.2, R5.2, R6.2, R7.2, R8.2, R9.2, R10.2, R11.2, R12.2, R13.2, R14.2, R15.2, R18.2, U1.2 (Bottom_Rail), U2.4 (GND), U3.3 (GND)
unnamed: A1.37 (3V3_EN), J4.17
unnamed: A1.35 (ADC_VREF), J4.15
unnamed: A1.1 (GPIO0), J1.1, R17.2
unnamed: A1.4 (GPIO2), J1.4
unnamed: A1.5 (GPIO3), J1.5
unnamed: A1.6 (GPIO4), J1.6
unnamed: A1.7 (GPIO5), J1.7
unnamed: A1.9 (GPIO6), J1.9
unnamed: A1.10 (GPIO7), J1.10
unnamed: A1.31 (GPIO26_ADC0), C3.1, J4.11, U2.6 (Vout), U3.4 (Vout)
unnamed: A1.32 (GPIO27_ADC1), J4.12
unnamed: A1.34 (GPIO28_ADC2), J4.14
unnamed: A1.30 (RUN), J4.10
unnamed: D1.2 (A), J3.2
unnamed: D2.3 (DIn), D3.1 (DOut)
unnamed: D3.3 (DIn), D4.1 (DOut)
unnamed: D4.3 (DIn), D5.1 (DOut)
unnamed: D5.3 (DIn), D6.1 (DOut)
unnamed: D6.3 (DIn), D7.1 (DOut)
unnamed: D7.3 (DIn), D8.1 (DOut)
unnamed: D8.3 (DIn), R18.1, R19.1
unnamed: D10.3 (DIn), D11.1 (DOut)
unnamed: D9.3 (DIn), D10.1 (DOut)
unnamed: D11.3 (DIn), D12.1 (DOut)
unnamed: D12.3 (DIn), D13.1 (DOut)
unnamed: D13.3 (DIn), D14.1 (DOut)
unnamed: D14.3 (DIn), D15.1 (DOut)
unnamed: D2.1 (DOut), D15.3 (DIn)
unnamed: J2.5 (Data), R17.1
unnamed: J2.4 (Vref), R16.2

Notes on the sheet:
I2C SCL
SPI SCK
SPI Rx
UART Tx
SPI Tx
Ability to choose or apply different voltage to power LEDs
Choice of breath sensor MP3V5004GP or BPS110 AD0P15
SPI CSn
I2C SDA

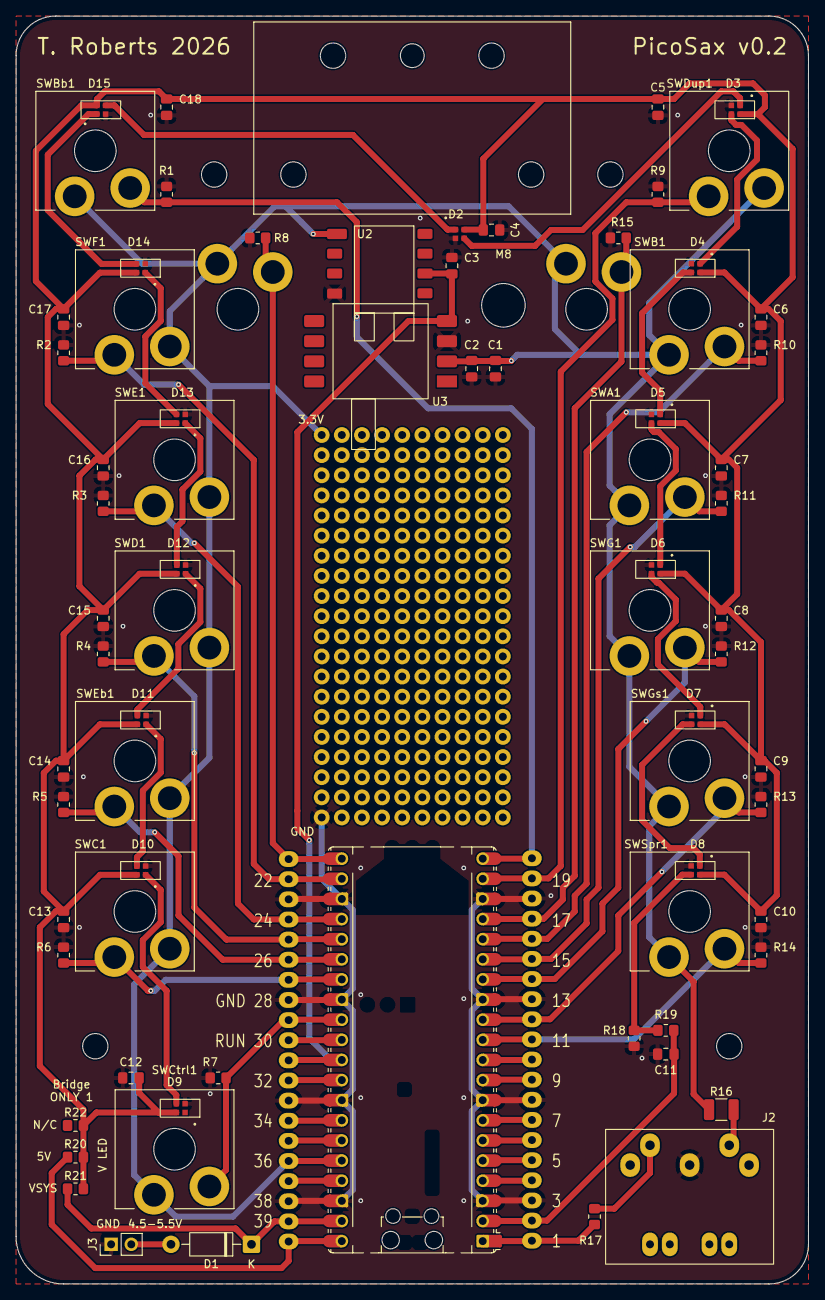
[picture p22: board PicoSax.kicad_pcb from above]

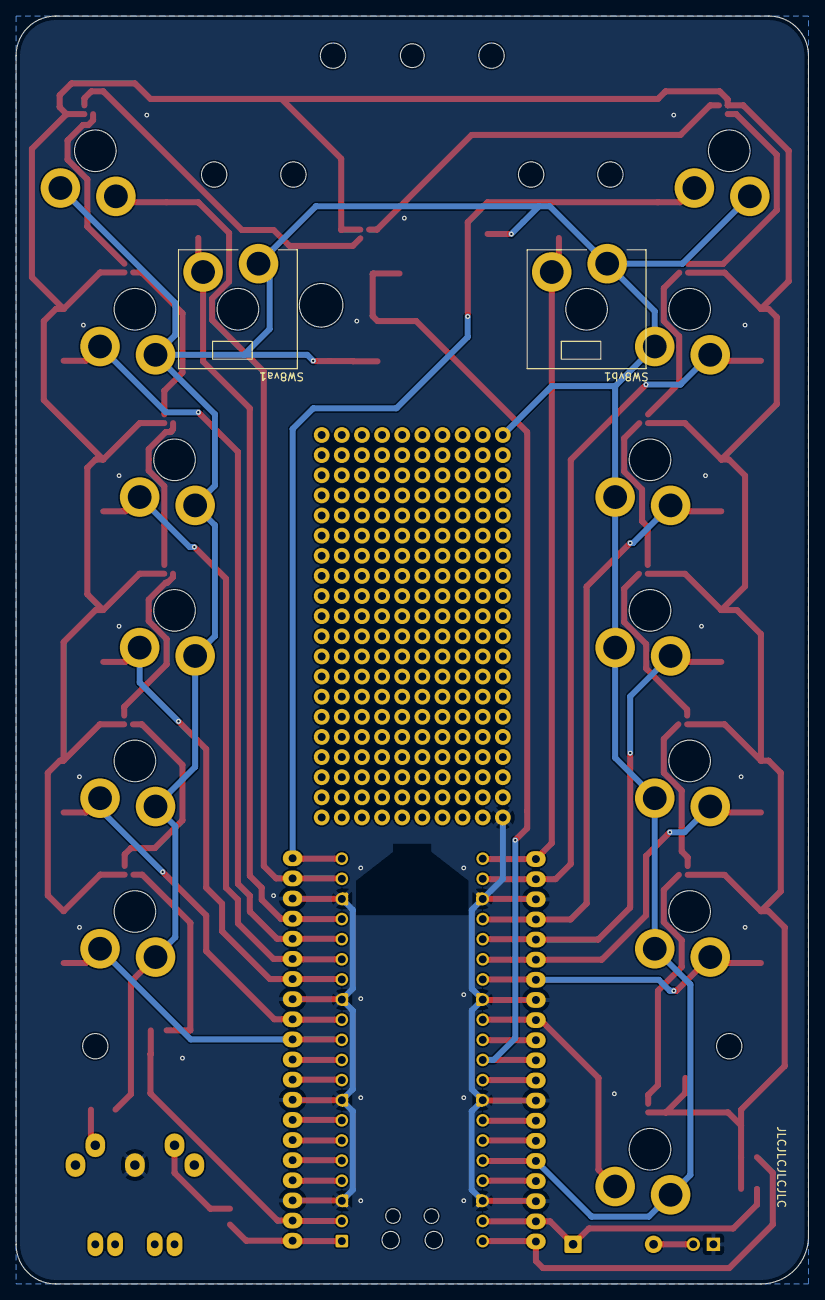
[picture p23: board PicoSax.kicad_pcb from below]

Board: 2 copper layers, 100.0 x 160.0 mm, 88 parts (2 on the bottom side), 51 nets.

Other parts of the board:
M1, M2, M3, M4, M5, M5#2, M6, M6#2: MountingHole_3.2mm_M3
M7: MountingHole_3mm
M8: MountingHole_5.5mm

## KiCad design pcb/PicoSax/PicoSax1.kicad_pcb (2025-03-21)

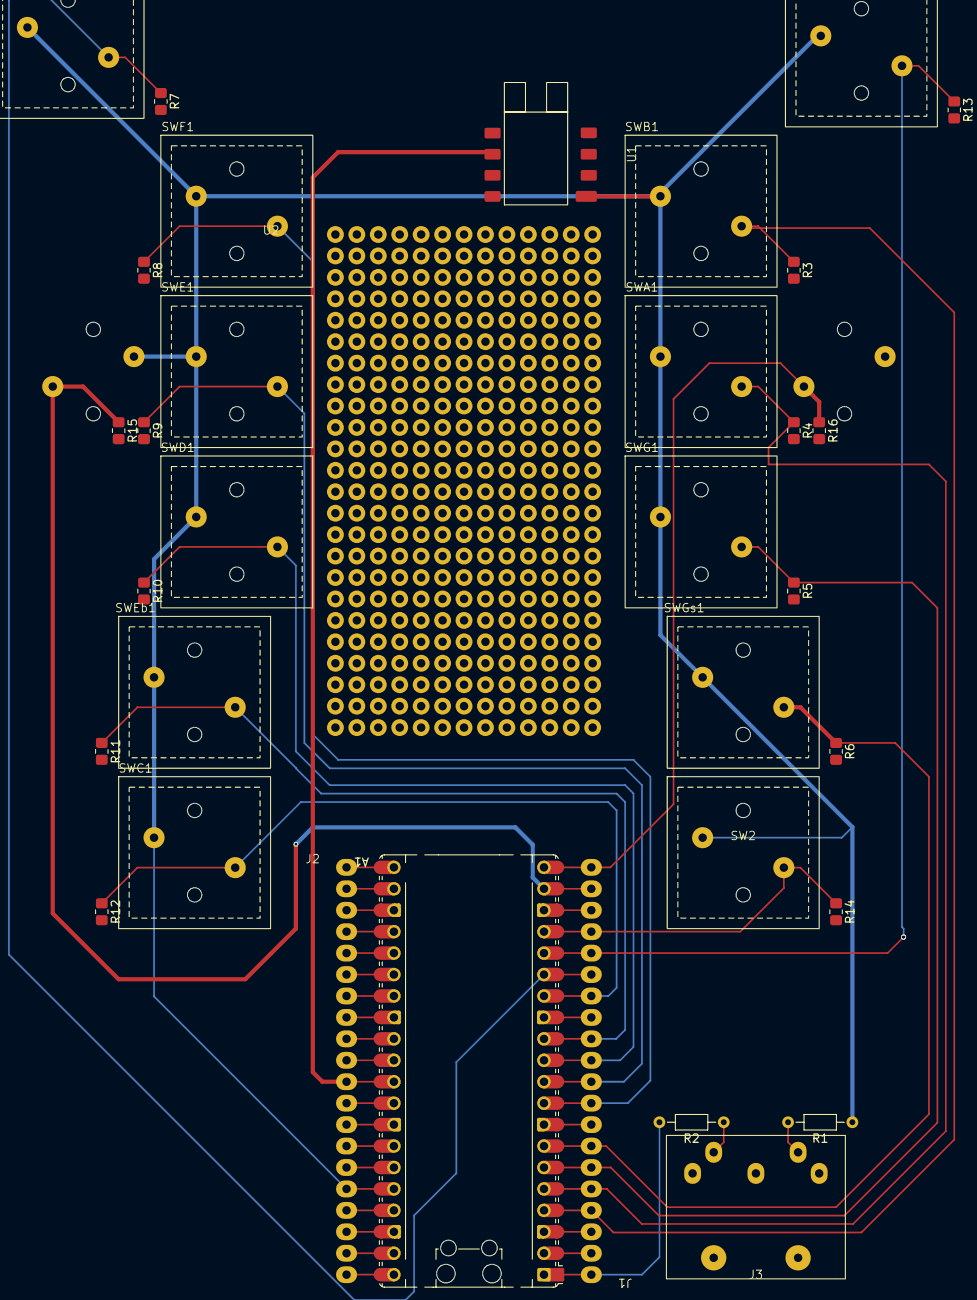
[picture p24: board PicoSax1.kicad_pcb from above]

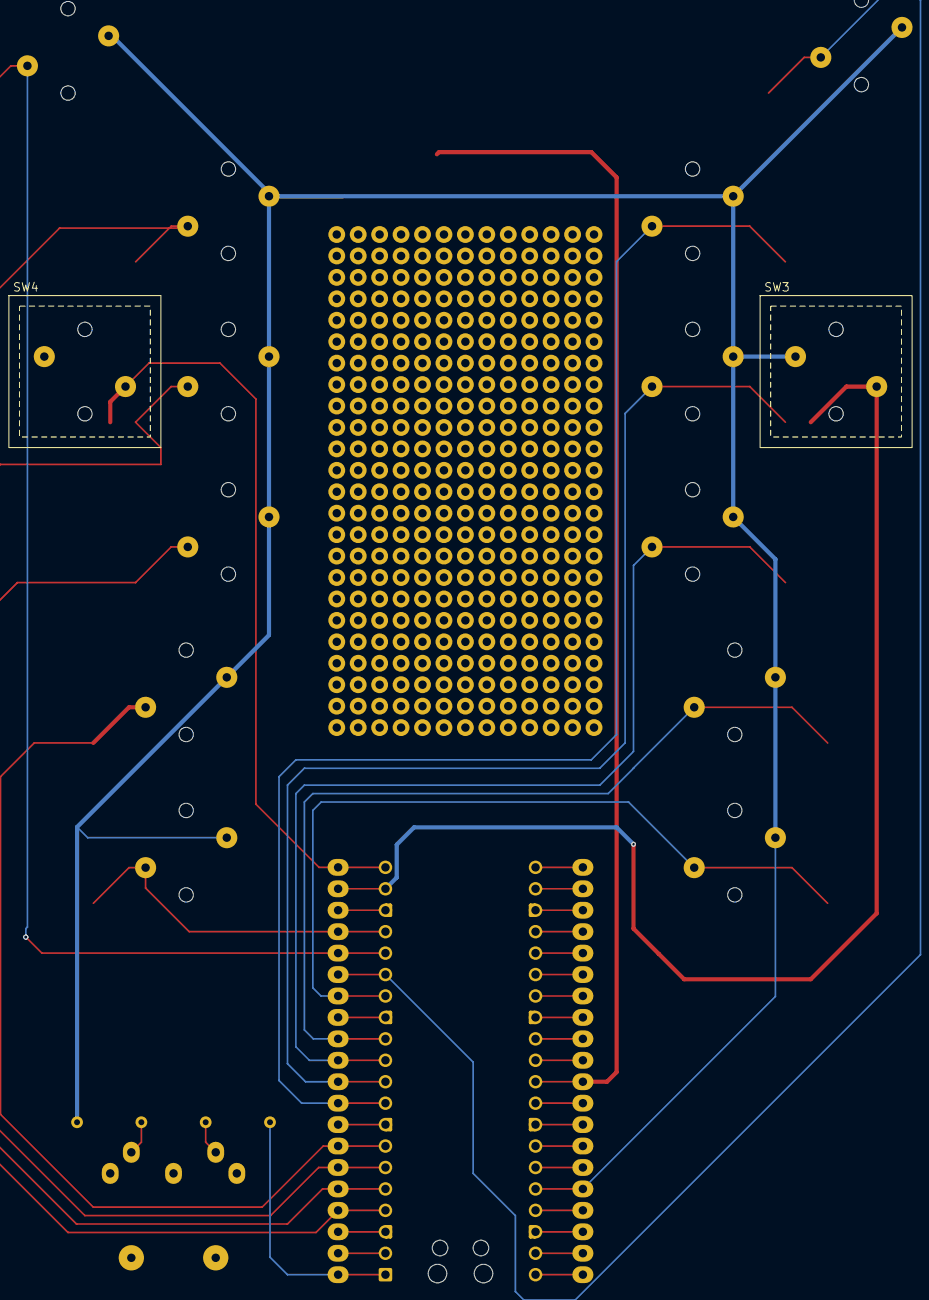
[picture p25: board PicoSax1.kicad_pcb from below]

Board: 2 copper layers, 36 parts (2 on the bottom side), 34 nets.

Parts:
A1: RaspberryPi_Pico; RaspberryPi_Pico_Common_Unspecified
J1, J2: PiPico Header
J3: MIDI_DIN5
R1: 33R 0.5W; R_Axial_DIN0204_L3.6mm_D1.6mm_P7.62mm_Horizontal
R2: 10R 0.25W; R_Axial_DIN0204_L3.6mm_D1.6mm_P7.62mm_Horizontal
R3, R4, R5, R6, R7, R8, R9, R10, R11, R12, R13, R14, R15, R16: 10K; R_0805_2012Metric_Pad1.20x1.40mm_HandSolder
SW1, SW2, SW3, SW4: Omron_B3K_L13L; Omron B3K L13L
SWA1: Omron_B3K_L13L; Omron B3K L13L
SWB1: Omron_B3K_L13L; Omron B3K L13L
SWBb1: Omron_B3K_L13L; Omron B3K L13L
SWC1: Omron_B3K_L13L; Omron B3K L13L
SWD1: Omron_B3K_L13L; Omron B3K L13L
SWE1: Omron_B3K_L13L; Omron B3K L13L
SWEb1: Omron_B3K_L13L; Omron B3K L13L
SWF1: Omron_B3K_L13L; Omron B3K L13L
SWG1: Omron_B3K_L13L; Omron B3K L13L
SWGs1: Omron_B3K_L13L; Omron B3K L13L
U1: BPS110 AD0P15
U2: Perfboard 13x24

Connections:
+3V3: A1.36 (3V3), J2.16, R1.1, SW1.1 (A), SW2.1 (A), SW3.1 (A), SW4.1 (A), SWA1.1 (A), SWB1.1 (A), SWBb1.1 (A), SWC1.1 (A), SWD1.1 (A), SWE1.1 (A), SWEb1.1 (A), SWF1.1 (A), SWG1.1 (A), SWGs1.1 (A), U1.1 (Vs)
GND: A1.3 (GND), A1.8 (GND), A1.13 (GND), A1.18 (GND), A1.23 (GND), A1.28 (GND), A1.33 (AGND), A1.38 (GND), J1.3, J1.8, J1.13, J1.18, J2.3, J2.8, J2.13, J2.18, J3.2 (Shield), R3.2, R4.2, R5.2, R6.2, R7.2, R8.2, R9.2, R10.2, R11.2, R12.2, R13.2, R14.2, R15.2, R16.2, U1.4 (GND)
unnamed: A1.37 (3V3_EN), J2.17
unnamed: A1.35 (ADC_VREF), J2.15
unnamed: A1.1 (GPIO0), J1.1, R2.2
unnamed: A1.4 (GPIO2), J1.4, R3.1, SWB1.2 (B)
unnamed: A1.5 (GPIO3), J1.5, R4.1, SWA1.2 (B)
unnamed: A1.6 (GPIO4), J1.6, R5.1, SWG1.2 (B)
unnamed: A1.7 (GPIO5), J1.7, R6.1, SWGs1.2 (B)
unnamed: A1.9 (GPIO6), J1.9, R8.1, SWF1.2 (B)
unnamed: A1.10 (GPIO7), J1.10, R9.1, SWE1.2 (B)
unnamed: A1.11 (GPIO8), J1.11, R10.1, SWD1.2 (B)
unnamed: A1.12 (GPIO9), J1.12, R11.1, SWEb1.2 (B)
unnamed: A1.14 (GPIO10), J1.14, R12.1, SWC1.2 (B)
unnamed: A1.15 (GPIO11), J1.15, R7.1, SWBb1.2 (B)
unnamed: A1.16 (GPIO12), J1.16, R13.1, SW1.2 (B)
unnamed: A1.17 (GPIO13), J1.17, R14.1, SW2.2 (B)
unnamed: A1.19 (GPIO14), J1.19, R15.1, SW3.2 (B)
unnamed: A1.20 (GPIO15), J1.20, R16.1, SW4.2 (B)
unnamed: A1.21 (GPIO16), J2.1
unnamed: A1.22 (GPIO17), J2.2
unnamed: A1.24 (GPIO18), J2.4
unnamed: A1.25 (GPIO19), J2.5
unnamed: A1.26 (GPIO20), J2.6
unnamed: A1.27 (GPIO21), J2.7
unnamed: A1.29 (GPIO22), J2.9
unnamed: A1.31 (GPIO26_ADC0), J2.11, U1.6 (Vout)
unnamed: A1.32 (GPIO27_ADC1), J2.12
unnamed: A1.34 (GPIO28_ADC2), J2.14
unnamed: A1.30 (RUN), J2.10
unnamed: A1.40 (VBUS), J2.20
unnamed: A1.39 (VSYS), J2.19
unnamed: J3.5 (Data), R2.1
unnamed: J3.4 (Vref), R1.2

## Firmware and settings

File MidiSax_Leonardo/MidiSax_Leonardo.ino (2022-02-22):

/*
 * MIDIUSB_test.ino
 *
 * Created: 4/6/2015 10:47:08 AM
 * Author: gurbrinder grewal
 * Modified by Arduino LLC (2015)
 * 
 * MIDI Saxophone by Timothy Roberts
 * 23 October 2020
 * 
 */ 

#include "MIDIUSB.h"


// Function prototypes
void noteOn(byte channel, byte pitch, byte velocity);
void noteOff(byte channel, byte pitch, byte velocity);
void controlChange(byte channel, byte control, byte value);
void PANIC(void);
void pinSetup(void);
int readNote(void);
void breathSetup(void);
int readBreath(void);

// Button define etc.
#define B_Button_Pin 2
#define A_Button_Pin 3
#define G_Button_Pin 4
#define Gs_Button_Pin 5
#define F_Button_Pin 6
#define E_Button_Pin 7
#define D_Button_Pin 8
#define Ds_Button_Pin 9

#define Breath_Pin A0
#define Breath_LED_Pin 11
#define Octave_Pin A1
#define Octave_LED_Pin 10

//#define MIDI_TX_Pin 1
//#define MIDI_RX_Pin 0

#define breath_threshold 15 //Breath on/off threshold
#define breath_scale 0.5 //Breath scaling factor
#define breath_array_len 8

float breath_rest = 0;
int prev_note = -1;
int prev_breath = 0;
bool note_on = 0;
int breath_raw = 0;
int breath_array[breath_array_len];


void setup() {
  Serial.begin(9600);
  pinSetup();
  breathSetup();
}

void loop() {
  int note = -1, breath_filt;
//  float breath = 0;
  breath_filt = readBreath();
  
  
//  Serial.println(breath_filt);
  analogWrite(Breath_LED_Pin,min(max(0,breath_filt<<1),255));
  controlChange(0, 2, min(127,max(0,breath_filt*2))); // Set the value of controller 2 (breath) on channel 0 to breath value
//  controlChange(0, 74, min(int(breath),127)); // Set the value of controller 74 (mpe) on channel 0 to breath value
  //controlChange(0, 7, min(breath,127)); // Set the value of controller 7 (volume) on channel 0 to breath value

  Serial.println(breath_filt);
  
  //Panic code
  if (breath_filt<-10){
    PANIC();
  }
  
  //Read the note value
  note = readNote();
  
  //Change note if needed
  //Need to figure out how to retrigger notes based on breath input

  // I have 2 variables to use here
  // breath_raw is the most recent breath value (converted to int)
  // breath_filt is the filtered breath value
  // Idea is to track the filtered value, and use the raw value to set velocity
  bool retrigger_flag = 0;

  if (breath_filt<breath_threshold){
    note_on = 0;
    noteOff(0, prev_note, min(127,max(0,breath_raw*2)));//);
    retrigger_flag = 0;
  }

  if (breath_filt>breath_threshold){
    retrigger_flag = 1;
  }
  
  if (note!=prev_note && note!=-1 || retrigger_flag && !note_on){ //&& breath>threshold
    //turn off previous note
    noteOff(0, prev_note, min(127,max(0,breath_raw*2)));//);  // Channel 0, middle C, normal velocity
    //MidiUSB.flush(); //Moved into the noteOn function
    note_on = 0;

    //turn on new note
    noteOn(0, note, min(127,max(0,breath_raw*2)));//min(127,max(0,int(breath*127))));   // Channel 0, middle C, normal velocity
    //MidiUSB.flush();  //Moved into the noteOn function
    note_on = 1;
    //Serial.println(note);

    prev_note = note;
  }
  prev_breath = breath_filt;
  delay(2); //Delay to reduce amount of midi data
  
  
}


// -----------------------Function definitions----------------------------------

// First parameter is the event type (0x09 = note on, 0x08 = note off).
// Second parameter is note-on/note-off, combined with the channel.
// Channel can be anything between 0-15. Typically reported to the user as 1-16.
// Third parameter is the note number (48 = middle C).
// Fourth parameter is the velocity (64 = normal, 127 = fastest).

void noteOn(byte channel, byte pitch, byte velocity) {
  midiEventPacket_t noteOn = {0x09, 0x90 | channel, pitch, velocity};
  MidiUSB.sendMIDI(noteOn);
  MidiUSB.flush(); //This forces the note to be sent
}

void noteOff(byte channel, byte pitch, byte velocity) {
  midiEventPacket_t noteOff = {0x08, 0x80 | channel, pitch, velocity};
  MidiUSB.sendMIDI(noteOff);
  MidiUSB.flush(); //This forces the note to be sent
}

// First parameter is the event type (0x0B = control change).
// Second parameter is the event type, combined with the channel.
// Third parameter is the control number number (0-119).
// Fourth parameter is the control value (0-127).

void controlChange(byte channel, byte control, byte value) {
  midiEventPacket_t event = {0x0B, 0xB0 | channel, control, value};
  MidiUSB.sendMIDI(event);
  MidiUSB.flush(); //This forces the note to be sent
}

void PANIC(void) {
  int n = 0,k = 0;
  for(k=0;k<16;k++){
    for(n=0;n<128;n++){
      midiEventPacket_t noteOff = {0x08, 0x80 | k, n, 0};
      MidiUSB.sendMIDI(noteOff);
      MidiUSB.flush(); //This forces the note to be sent
    }
  }
}

void pinSetup(void){
  int n = 0;
  for(n=B_Button_Pin;n<Ds_Button_Pin;n++){
    pinMode(n,INPUT);
  }
  pinMode(Breath_LED_Pin, OUTPUT);
  pinMode(Octave_LED_Pin, OUTPUT);
}

void breathSetup(void){
  breath_rest = analogRead(Breath_Pin);
  int n = 0, num_run = 100;
  for(n=0;n<num_run;n++){
    breath_rest = (breath_rest+float(analogRead(Breath_Pin)))/2;
  }
  breath_rest = breath_rest/1024; //Convert to range 0-1
}

int readBreath(void){
  //breath_array
  float breath = 0;
  int n;
  int breath_sum = 0, breath_filt=0;
  //Read the breath sensor value
  breath = (float(analogRead(Breath_Pin))/1024-breath_rest); //Remove atmospheric pressure
  //Scale the breath input
  if(breath<0){
    breath = -1*pow(-1*breath,breath_scale);
  }else{
    breath = pow(breath,breath_scale);
  }
  breath_raw = min(127,max(0,int(breath*127)));

  //breath_array
  //adjust breath array
  // Shift values right through the breath array
  // Using pointers because I couldn't get normal array indexing to work
  for (n=0;n<breath_array_len-1;n++){
    *(breath_array+n) = *(breath_array+(n+1));
  }

//  breath_array[breath_array_len-1] = temp_breath;
  *(breath_array+breath_array_len-1) = breath_raw;
  for (n=0;n<breath_array_len;n++){
    breath_sum = breath_sum + *(breath_array+n);
//    Serial.print(*(breath_array+n));
//    Serial.print(",");
  }
//  Serial.print("\n");
  breath_filt = breath_sum/breath_array_len;
//  Serial.print(temp_breath);
//  Serial.print("\t");
//  Serial.print(breath_sum);
//  Serial.print("\t");
//  Serial.println(breath_filt);
  return breath_filt;
}


int readNote(void){
  //Notes for later
//  Pin 2(B): Port PD1
//  Pin 3(A): Port PD0
//  Pin 4(G): Port PD4
//  Pin 5(Gs): Port PC6
//  Pin 6(F): Port PD7
//  Pin 7(E): Port PE6
//  Pin 8(D): Port PB4
//  Pin 9(Ds): Port PB5
  byte note_byte = 0;
  int note = -1;
  note_byte = note_byte | (PIND & B00000010)>>1; //B
  note_byte = note_byte | (PIND & B00000001)<<1; //A
  note_byte = note_byte | (PIND & B00010000)>>2; //G
  note_byte = note_byte | (PINC & B01000000)>>3; //Gs
  note_byte = note_byte | (PIND & B10000000)>>3; //F
  note_byte = note_byte | (PINE & B01000000)>>1; //E
  note_byte = note_byte | (PINB & B00010000)<<2; //D
  note_byte = note_byte | (PINB & B00100000)<<2; //Ds
//  Serial.print(note_byte);
//Switch case to get note value
  switch (note_byte){
    case 0:
    //C#
      note = 61;
      break;
    case 2:
    //C
      note = 60;
      break;
    case 1:
    //B
      note = 59;
      break;
    case 19:
    //A#
      note = 58;
      break;
    case 3:
    //A
      note = 57;
      break;
    case 15:
    //G#
      note = 56;
      break;
    case 7:
    //G
      note = 55;
      break;
    case 39:
    //F#
      note = 54;
      break;
    case 23:
    //F
      note = 53;
      break;
    case 55:
    //E
      note = 52;
      break;
    case 247:
    //D#
      note = 51;
      break;
    case 119:
    //D
      note = 50;
      break;
    default:
      note = -1;
  }
//  Serial.print("\t");
//  Serial.println(note);

// Adjust the octave
  int octave_read = 0;
  octave_read = analogRead(Octave_Pin);
  if (octave_read>512){
    //top octave
    note += 24;
    analogWrite(Octave_LED_Pin, 255);
  }else if(octave_read>50){
    //middle octave
    note += 12;
    analogWrite(Octave_LED_Pin, 64);
  }else{
    //bottom octave
    //note +=0;
    analogWrite(Octave_LED_Pin, 0);
  }
return note;
}

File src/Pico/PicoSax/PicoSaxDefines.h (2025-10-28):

//Pin Assignment
// Pin	    Function	    Connection
// 1	    GPIO 0	        UART Tx
// 2	    GPIO 1	        LEDs
// 3	    GND	
// 4	    GPIO 2	        SPI SCK | UART 1 Tx
// 5	    GPIO 3	        SPI Tx | UART 1 Rx
// 6	    GPIO 4	        SPI Rx
// 7	    GPIO 5	        SPI CSn
// 8	    GND	
// 9	    GPIO 6	        I2C SDA
// 10	    GPIO 7	        I2C SCL
// 11	    GPIO 8	        Spr
// 12	    GPIO 9	        Gs
// 13	    GND	
// 14	    GPIO 10	        G
// 15	    GPIO 11	        A
// 16	    GPIO 12	        B
// 17	    GPIO 13	        8va
// 18	    GND	
// 19	    GPIO 14	        Dup
// 20	    GPIO 15	        Bb
// 21	    GPIO 16	        Bvb
// 22	    GPIO 17	        F
// 23	    GND	
// 24	    GPIO 18	        E
// 25	    GPIO 19	        D
// 26	    GPIO 20	        Eb
// 27	    GPIO 21	        C
// 28	    GND	
// 29	    GPIO 22	        Ctrl
// 30	    RUN	
// 31	    GPIO 26 | ADC0	Breath
// 32	    GPIO 27 | ADC1	
// 33	    AGND	
// 34	    GPIO 28 | ADC2	
// 35	    ADC_VREF	
// 36	    3V3	
// 37	    3V3 EN	
// 38	    GND	
// 39	    VSYS	
// 40	    VBUS	        5V (USB)

#define VERBOSE 0
#define BREATH_GPIO 26

#define breath_threshold 20 //Breath on/off threshold
#define breath_scale 0.5 //Breath scaling factor
#define breath_array_len 8
#define NEW_NOTE_TIMER 30000 //uS

#define CC_threshold 1
#define breath_CC 2

// UART defines
// By default the stdout UART is `uart0`, so we will use the second one
#define UART_ID uart0  //uart1
#define BAUD_RATE 31250// 31250 MIDI Baud // 115200 USB BAUD
#define DATA_BITS 8
#define STOP_BITS 1
#define PARITY UART_PARITY_NONE

// Use pins 4 and 5 for UART1
// Pins can be changed, see the GPIO function select table in the datasheet for information on GPIO assignments
#define UART_TX_PIN 0 //4
#define UART_RX_PIN 1 //5

// Global variables
float breath_at_rest = 0;
float breath_array[breath_array_len];
char prev_note = 0;
bool note_on = 0;
uint8_t breath_raw_midi = 0;
int prev_breath = 0;
uint8_t prev_CC = 0;
uint8_t current_CC = 0;
int8_t octave_transpose = 1;
int8_t octave_move = 0;
uint8_t semitone_transpose = 0;
bool menu = 0;

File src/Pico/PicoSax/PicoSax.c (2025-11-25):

#include <stdio.h>
#include <math.h>
#include "pico/stdlib.h"
#include "hardware/pio.h"
#include "hardware/uart.h"
#include "hardware/gpio.h"
#include "hardware/adc.h"
#include "pico/time.h"
#include "pico/binary_info.h" //USBMIDI


#include "PicoSaxDefines.h"
#include "PicoSaxFunc.h"

#include "bsp/board.h" //USBMIDI
#include "tusb.h" //USBMIDI

enum  {
  BLINK_NOT_MOUNTED = 250,
  BLINK_MOUNTED = 1000,
  BLINK_SUSPENDED = 2500,
};

static uint32_t blink_interval_ms = BLINK_NOT_MOUNTED;
const uint LED_PIN = PICO_DEFAULT_LED_PIN;

void midi_task(void);

absolute_time_t current_time, last_note_time;

int main()
{
    //stdio_init_all();
    
    // tusb_init();
    // PicoSax Setup
    setupBoard();
    // Setup ADC pin for breath input
    adc_init();
    adc_gpio_init(BREATH_GPIO);
    adc_select_input(0);
    setupBreath();
    // Set up our UART
    // gpio_set_function(UART_TX_PIN, UART_FUNCSEL_NUM(uart0, 0));
    // gpio_set_function(UART_RX_PIN, UART_FUNCSEL_NUM(uart0, 1));
    // uart_init(UART_ID, BAUD_RATE);

    board_init(); //USBMIDI
    tusb_init(); //USBMIDI
    

    while (true)
    {
        tud_task(); // tinyusb device task
        uint8_t msg[3];
        uint8_t test_cc_msg[] = {0xB0,74,64};

      // Get the input data
        uint8_t note_midi, debounce_midi, test_midi_note;
        note_midi = readButtons();

        // //debounce moving of multiple keys
        //     //test_midi_note = note_midi;
        //     sleep_ms(10);
        //     debounce_midi  = readButtons();           
        //     while(debounce_midi != note_midi){
        //       note_midi = debounce_midi;
        //       sleep_ms(10);
        //       debounce_midi  = readButtons();
        //     }


        uint8_t breath_filt;
        breath_filt = readBreath();
        //printf("%d\t",breath_filt);
        // Set CC2 to breath value
        current_CC = breath_filt;
        if (fabs(current_CC - prev_CC) > CC_threshold){
            //  // Set the value of controller 2 (breath) on channel 0 to breath value
            // //MIDICC(0,breath_CC, breath_raw_midi);
            msg[0] = 0xB0; //Midi CC channel 1
            msg[1] = breath_CC ;
            msg[2] = breath_filt ;
            tud_midi_n_stream_write(0, 0, msg, 3);
            prev_CC = current_CC;
        }

        //-----------Sending MIDI message if needed----------
        //bool retrigger_flag = 0;

        //Note Logic
        // This used to be multiple individual section.  Reformat to be branching.
        if (breath_filt < breath_threshold ){
          //Turning Note Off
          if ( note_on == 1){
            note_on = 0;
            gpio_put(PICO_DEFAULT_LED_PIN, 0);
            // MIDInoteOff(1, prev_note, breath_raw_midi);
            msg[0] = 0x80;                    // Note Off - Channel 1
            msg[1] = prev_note; // Note Number
            msg[2] = breath_filt;                       // Velocity
            tud_midi_n_stream_write(0, 0, msg, 3);
            //last_note_time = get_absolute_time();

            //retrigger_flag = 0;
          }
            
        }else{
          //Breath is above the threshold
          gpio_put(PICO_DEFAULT_LED_PIN, 1);
          if(note_midi >= 0 && note_midi < 128){
            //Valid Key Combo
            if(note_on == 0){
              //No current note, so start one
              note_on = 1;
              // turn on new note
              msg[0] = 0x90;                    // Note On - Channel 1
              msg[1] = note_midi;                // Note Number
              msg[2] = breath_raw_midi;           // Velocity
              tud_midi_n_stream_write(0, 0, msg, 3);
              prev_note = note_midi;

            }else{
              //Note is already on
              if (note_midi != prev_note){
                //MIDI CC74 when new note
                // test_cc_msg[2] = 127;
                // tud_midi_n_stream_write(0, 0, test_cc_msg, 3);
                //New note is different to the old note, so there is a changing note
//Make sure that the new note is the final note.  Should be settled after 25ms
                //sleep_ms(50);
                test_midi_note = readButtons();
                //get the current time
                current_time = get_absolute_time();
                //IShould really just keep comparing as time passess, rather than waiting every time
                while(note_midi != test_midi_note || (get_absolute_time()-current_time <NEW_NOTE_TIMER)){
                  //sleep_ms(50);
                  //We want the note to be the same and the time to be greater than the threshold
                  //So store the new note
                  if (test_midi_note != note_midi){
                    //Reset the timer
                    current_time = get_absolute_time();
                    //Save the new note
                    note_midi = test_midi_note;
                    //pulse CC74
                    // test_cc_msg[2] = 0;
                    // tud_midi_n_stream_write(0, 0, test_cc_msg, 3);
                    // test_cc_msg[2] = 127;
                    // tud_midi_n_stream_write(0, 0, test_cc_msg, 3);
                  }
                  
                  //What is the note?
                  test_midi_note = readButtons();
                }
                //Legato note change
                //Turn off CC74 because the note has settled.
                // test_cc_msg[2] = 0;
                // tud_midi_n_stream_write(0, 0, test_cc_msg, 3);
                // turn on new note
                msg[0] = 0x90;                    // Note On - Channel 1
                msg[1] = note_midi;                // Note Number
                msg[2] = breath_raw_midi;           // Velocity
                tud_midi_n_stream_write(0, 0, msg, 3);
                
                //does there need to be a delay?
                sleep_ms(1);

                //turn off old note
                msg[0] = 0x80;                    // Note Off - Channel 1
                msg[1] = prev_note; // Note Number
                msg[2] = breath_raw_midi;                       // Velocity
                tud_midi_n_stream_write(0, 0, msg, 3);

                //Set the new note as previous note
                prev_note = note_midi;
                //No need to set note on, as it is already on.
                note_on = 1; // Just set it anyway.
                if(VERBOSE){
                  // printf("%d\n",note_midi);
                }
              }
            }
          }
        }
        //prev_breath = breath_filt; 
        //sleep_ms(50); // Delay to reduce amount of midi data
    }
}


//--------------------------------------------------------------------+
// Device callbacks
//--------------------------------------------------------------------+

// Invoked when device is mounted
void tud_mount_cb(void)
{
  blink_interval_ms = BLINK_MOUNTED;
}
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

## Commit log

2022-02-28 Added Schematic
2022-03-24 Working Leonardo
    [Sax_details.xlsx]
2022-03-29 Schematic Update
2022-04-06 G# fingerings and Menu
    [Sax_details.xlsx]
2025-03-19 v3 PCB
    KiCAD PCB for v3
    [Sax_details.xlsx]
2025-03-19 KiCAD Backup
    Ready for production
2025-03-21 Tubing Hole and BOM
    [19-C47RSGHBHC-5V012T_EVE.step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]
2025-03-24 Clean and Parts BOM
    [PicoSax Digikey Order 1 Unit.xlsx, PicoSax Digikey Order 2 Units.xlsx, PicoSax.csv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]
2025-03-25 PCB v0.11
    [PicoSax-B_Cu.gbl, PicoSax-B_Mask.gbs, PicoSax-B_Paste.gbp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]
2025-03-29 Pico Byte Values
    [Sax_details.xlsx]
2025-04-07 SVG and STEP
    [PicoSax.step]
2025-05-06 LED code
    [PIO 19C47 LED timing.xlsx]
2025-05-08 v0.2
    Updated LED footprint to have correct pin numbering. Redid layout and traces. Added helpful silkscreen for pi pico. Added some datasheets.
    [PicoSax.kicad_pcb, PicoSax.kicad_sch]
2025-05-08 v0.2 Silkscreen
    [PicoSax.kicad_pcb]
2025-05-12 PicoSax SRC
    [Sax_details.xlsx]
2025-05-20 3D and USBuart
    [Bottom.FCStd, PCB.FCStd, PicoSaxv0.1.FCStd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]
2025-05-31 Working
    Notes are changing too fast, causing issues if more than one key changes state.
    [PicoSax.c, PicoSaxDefines.h, PicoSaxFunc.h]
2025-08-14 move air pressure
    [MouthpieceTest.FCStd, PicoSax.kicad_pcb, PicoSax.kicad_sch]
2025-10-20 Mouthpiece mounting hole update
    [MouthpieceV2.FCStd, PicoSax.kicad_pcb, PicoSax.kicad_sch]
2025-10-24 USB MIDI minor PCB tweaks
    [PicoSax.kicad_pcb]
2025-10-28 Cross Fingering fix-ish
    Reformatted code to be nested if statements to make it easier to read and manage each case, rather than using flags.
    Note debouncing now waits for the note to be steady for 30mS, rather than waiting every time there's a new note to check again. 30mS is borderline not long enough, but it would make fast grace notes or trills not as effective.
    [PicoSax.c, PicoSaxDefines.h, PicoSaxFunc.h]
2025-10-29 MIDI Learn specific CC
    Also explored CC outputs on note change to confirm new note wait. Removed as they stopped other notes triggering.
    Occasionally a grace note or trill will be missed due to the wait.
    [Sax_Fingering_details.xlsx]
2025-11-20 Fix Midi Note 0
    Also added another Bb fingering
    Added research into trills.
    [Sax_Fingering_details.xlsx, Trill Files Database.xlsx]
2025-11-25 Fixed midi note overflow
    [PicoSax.c, PicoSaxFunc.h]
2026-01-14 KS-33 Update
    Routing still required. If wanting to work on previous version, see Backup.
    [PicoSax.kicad_pcb, PicoSax.kicad_sch]
2026-01-15 Partial Route
    [PicoSax.kicad_pcb, PicoSax.kicad_sch]
2026-01-15 Routing Complete
    Still need to adjust locations of component references. And there is an issue in DRC about the footprints not matching. Not sure why that is as it wasn't a problem yesterday.
    [PicoSax.kicad_pcb]
2026-03-24 V2 ready
    [PicoSax.kicad_pcb, PicoSax.kicad_sch]
